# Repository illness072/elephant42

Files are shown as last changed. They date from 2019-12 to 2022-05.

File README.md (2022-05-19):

# elephant42 (🐘42)

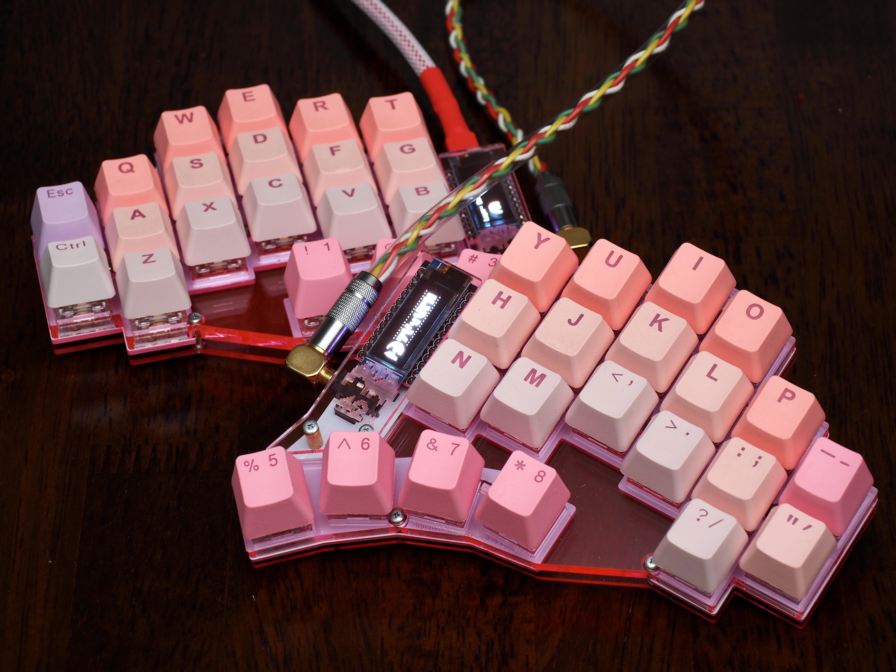
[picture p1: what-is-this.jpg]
what-is-this


## plates

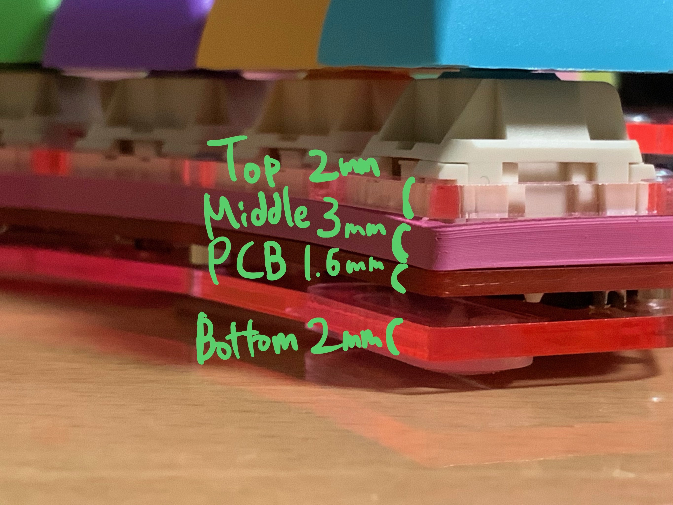
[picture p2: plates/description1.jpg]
plate1
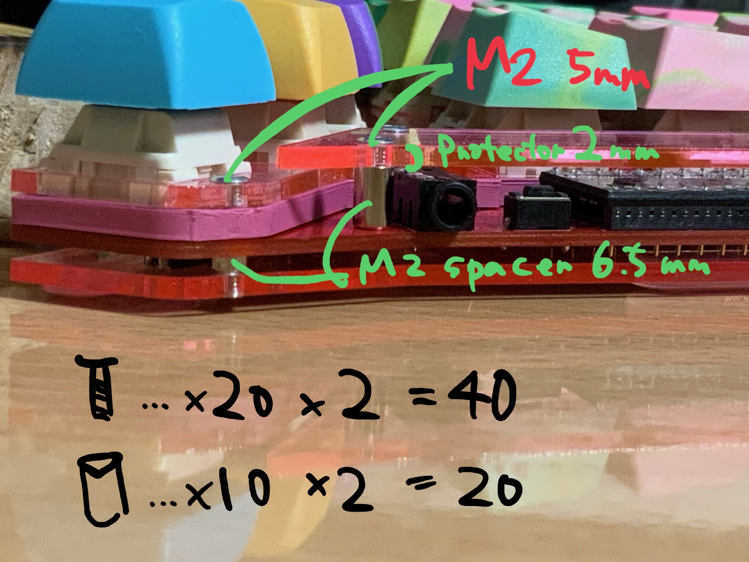
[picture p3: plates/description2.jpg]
plate2
|||
|--|--|
|dxf data in plates/|sandwitch mount with 6.5mm spacer|

## pcb

dependency on

  - https://github.com/foostan/kbd/tree/master/kicad-footprints/kbd.pretty

## cases

currently, not compatible with some switches.

## assembly

- [Build Guide (Japanese)](docs/build-guide.md)
- [Build Guide (English)](docs/build-guide-english.md)

## license?

Beerware!!

Come drink beer in Tokyo with me!! 🍺🍺🍺

## poor english?

Sorry, it's Google Translate.

# A small favor.

Could you generate a Gerber file from the origin/footprint branch and actually manufacture the PCB? 
We have implemented a fix for the footprint library link error and KiCAD6 support, but we have not yet been able to manufacture a PCB and test that it really works.
I would be most grateful if you could actually manufacture the PCB based on the footprint branch, check that it works, and report the results to me via Issue in this repository, my twitter, etc.
Thanks in advance.

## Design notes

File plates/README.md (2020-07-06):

# elephant42 アクリルプレートデータ

## トッププレートおよびボトムプレート、Pro Micro 保護プレート

acril-cut-2mm-A4.dxf

- トッププレートおよびボトムプレート、Pro Micro 保護プレートのカットデータです。
- 外枠が A4 サイズ、カット線を赤で作成しています
- 彫刻はありません。お好みに応じて追加してください
- プレート厚は 2mm を指定してください。

## ミドルプレート

acril-cut-3mm-A5.dxf

- ミドルプレートと、おまけで Pro Micro 保護プレートの厚め版をカットできるデータです
- 外枠が A5 サイズ、カット線を赤で作成しています
- 彫刻はありません。お好みに応じて追加してください
- プレート厚は 3mm を指定してください。

middle-plate-3Dprint.stl

- ミドルプレートの 3D プリントデータです。
  - 不透明素材にも対応するため、アクリルカット版のミドルプレートとは形状が異なります

## (発注用データ)

yusha/

- 実際に遊舎工房に発注するのに使用しているデータです。
  - 管理が面倒なので一緒に置いてますが、使うことはないと思います。

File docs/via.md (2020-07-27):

# VIA 対応ファームウェア

上記をどれだけ頑張っても**どーーーーーしても**環境構築がうまくいかない、コマンドラインにアレルギーがある、
GUI以外を使うわけにいかない事情がある等という方のために、VIA対応ファームウェアを用意しておきました。

[elephant42_via.hex](https://raw.githubusercontent.com/illness072/elephant42/master/via/elephant42_via.hex)

をダウンロードし、

[（初心者編）自作キーボードにファームウェアを書き込む - 自作キーボード温泉街の歩き方](https://salicylic-acid3.hatenablog.com/entry/qmk-toolbox)

を参考にファームウェアを書き込み、

[（初心者編）VIAを使ってキーマップを書き換えよう - 自作キーボード温泉街の歩き方](https://salicylic-acid3.hatenablog.com/entry/via-manual)

を参考にキーマップをいじることができます。

ただし、こちらの方法については

- QMK が提供するオフィシャルな手法ではない
- ファームウェアサイズが肥大化し、OLED ドライバサポートと共存させることができない
- ProMicro の EEPROM 書き込み回数を不用意に浪費しそうで怖い
- 何か問題が起きたときのトラブルシュートがやり辛い
- GUIであることが初心者向けであるとは限らない
- けっきょくQMKをわかってないと(特に40%以下のキーボードの設定は)厳しい
- 簡易ではあるが不完全な方法を安直に勧めるのはむしろ初心者をばかにしている

など、さまざまな問題点・懸念点があると考えており、何より elephant42 作者である私の好みではない理由により、**非推奨・サポート対象外** とさせて頂きます。

一時的な対処に使う場合や、どうしてもダメだったときの保険程度の手段と考えて、まずは QMK 本来の使用法を習熟するよう頑張ってみてください。

なお上級者の方がわかった上で運用する分には何の問題もありません。

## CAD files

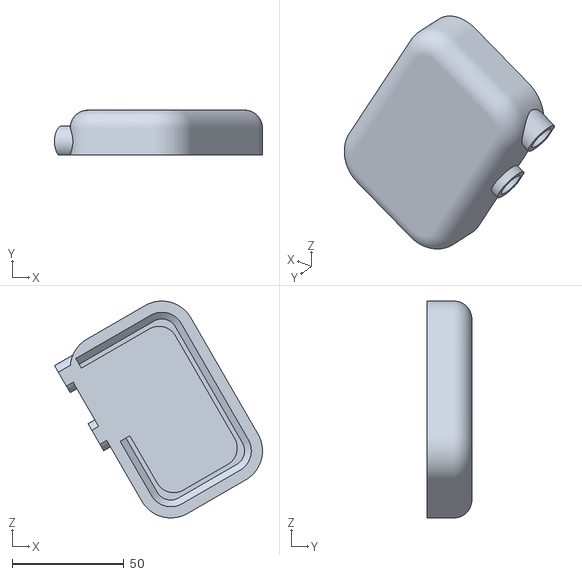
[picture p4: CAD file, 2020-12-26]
cases/v2/parmlestR.stl
93.0 x 20.0 x 97.0

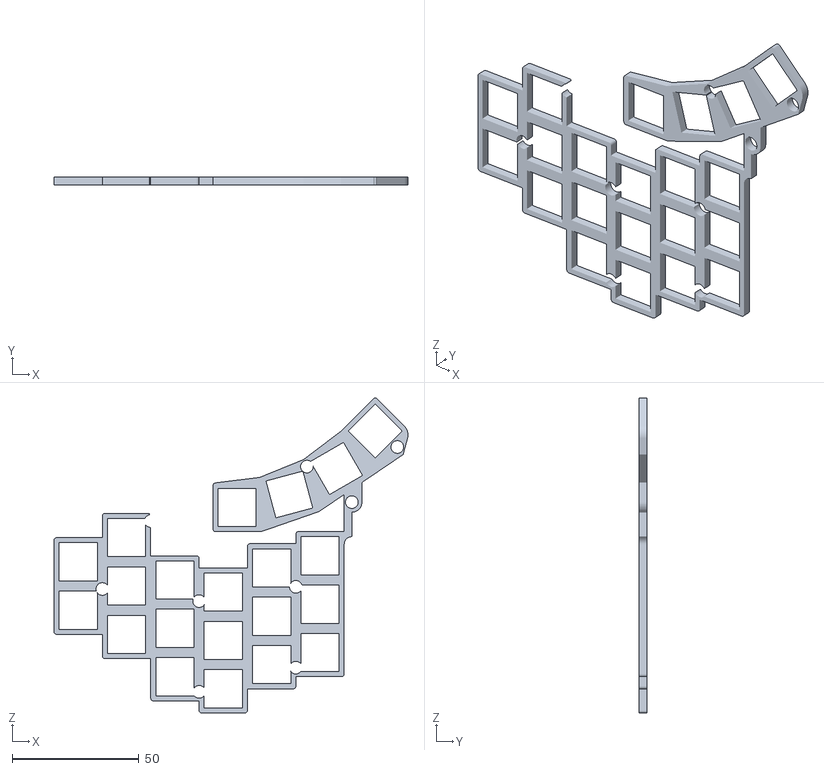
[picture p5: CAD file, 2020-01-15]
plates/middle-plate-3Dprint.stl
139.4 x 3.00 x 124.0

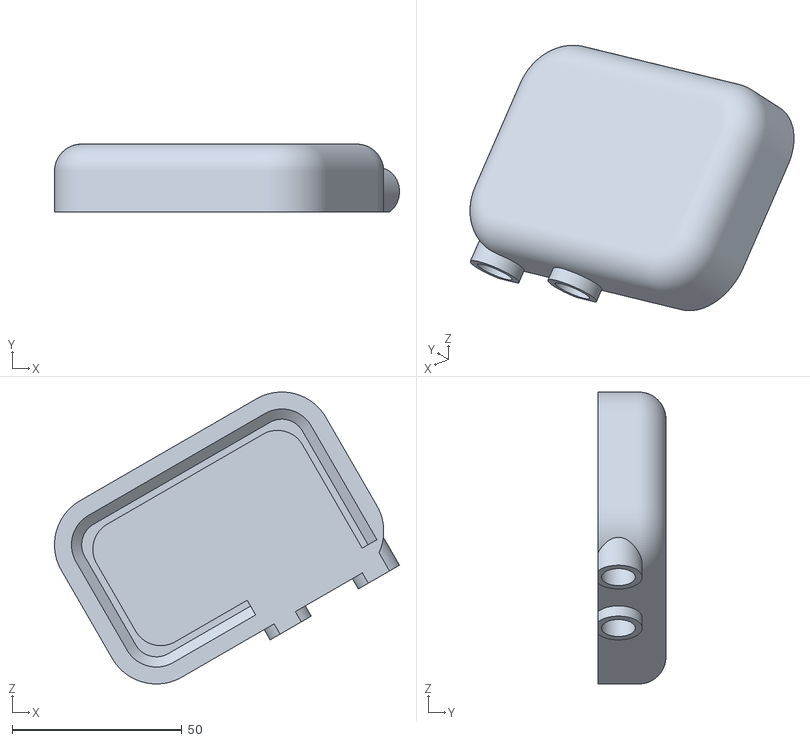
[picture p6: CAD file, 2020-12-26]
cases/v2/parmlestL.stl
101.6 x 20.0 x 86.0

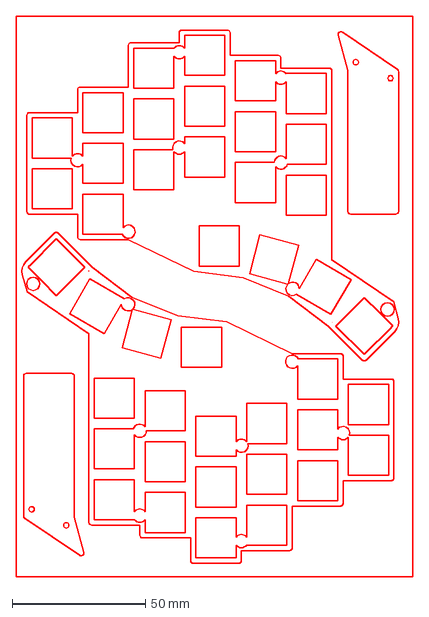
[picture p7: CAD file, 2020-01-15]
plates/acril-cut-3mm-A5.dxf
148.5 x 210.0 mm

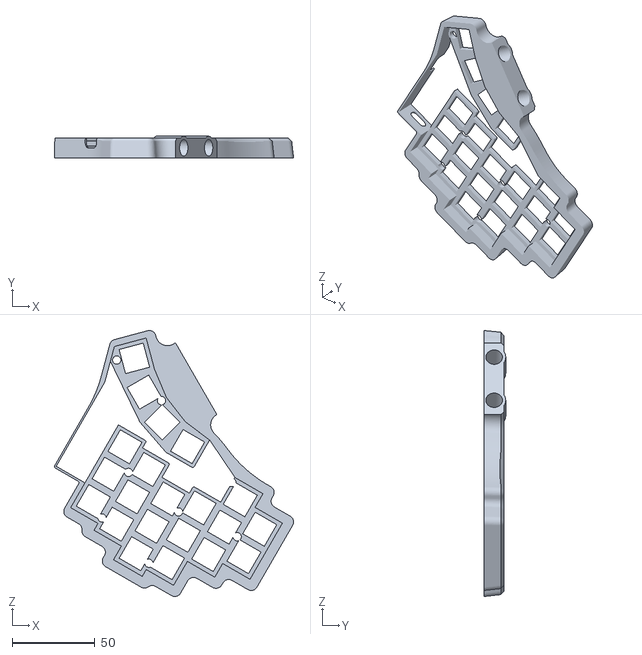
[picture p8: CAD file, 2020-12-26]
cases/v2/hangerR.stl
144.3 x 13.0 x 160.4

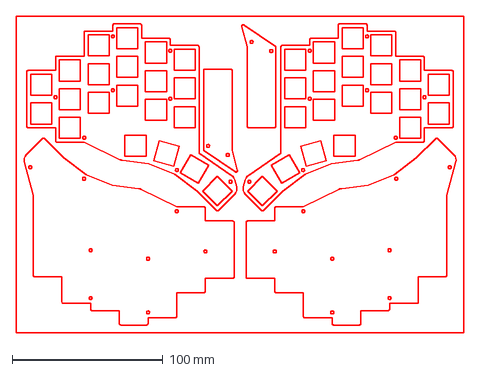
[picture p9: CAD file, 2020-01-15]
plates/acril-cut-2mm-A4.dxf
297.0 x 210.0 mm

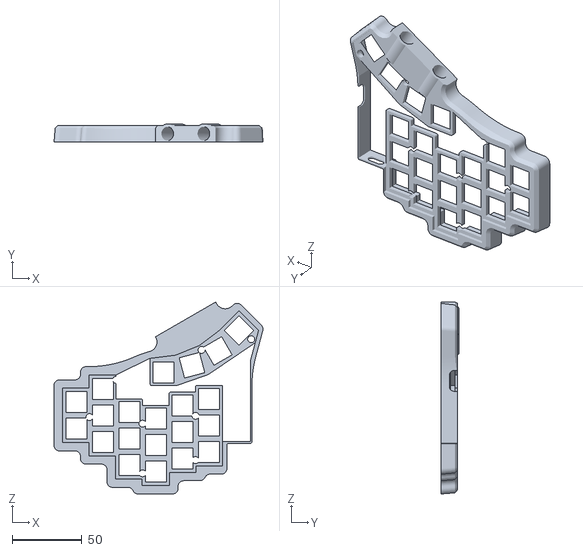
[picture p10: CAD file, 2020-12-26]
cases/v2/hangerL.stl
150.2 x 13.0 x 138.0

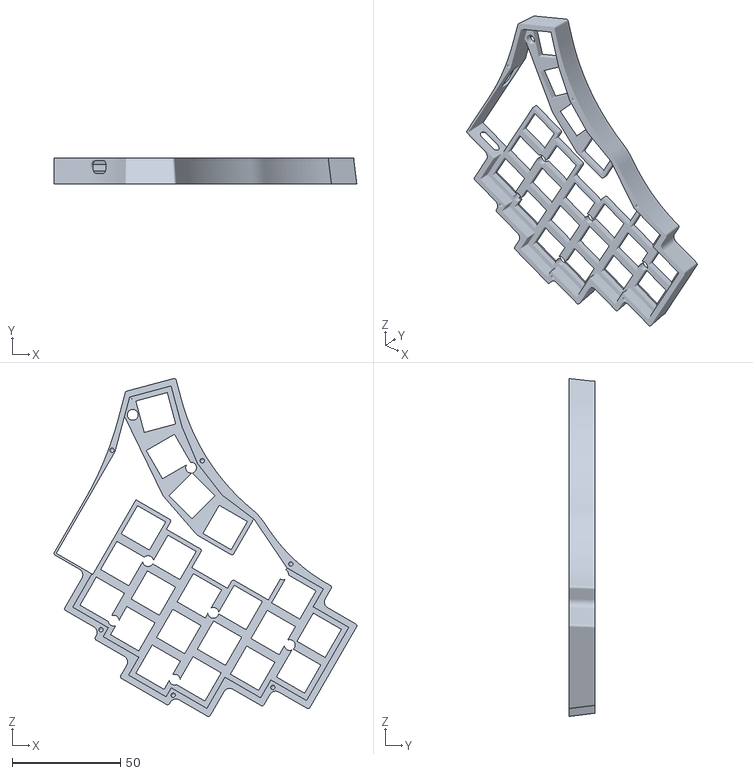
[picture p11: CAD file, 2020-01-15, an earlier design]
cases/v0/middle-hanger_R.stl
140.0 x 12.2 x 156.4

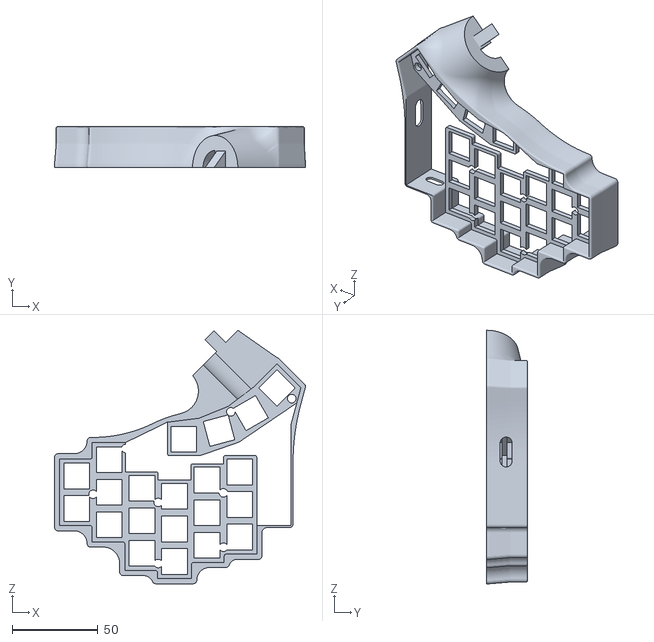
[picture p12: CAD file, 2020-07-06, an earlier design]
cases/v1/hanger-L.stl
146.8 x 24.0 x 148.3

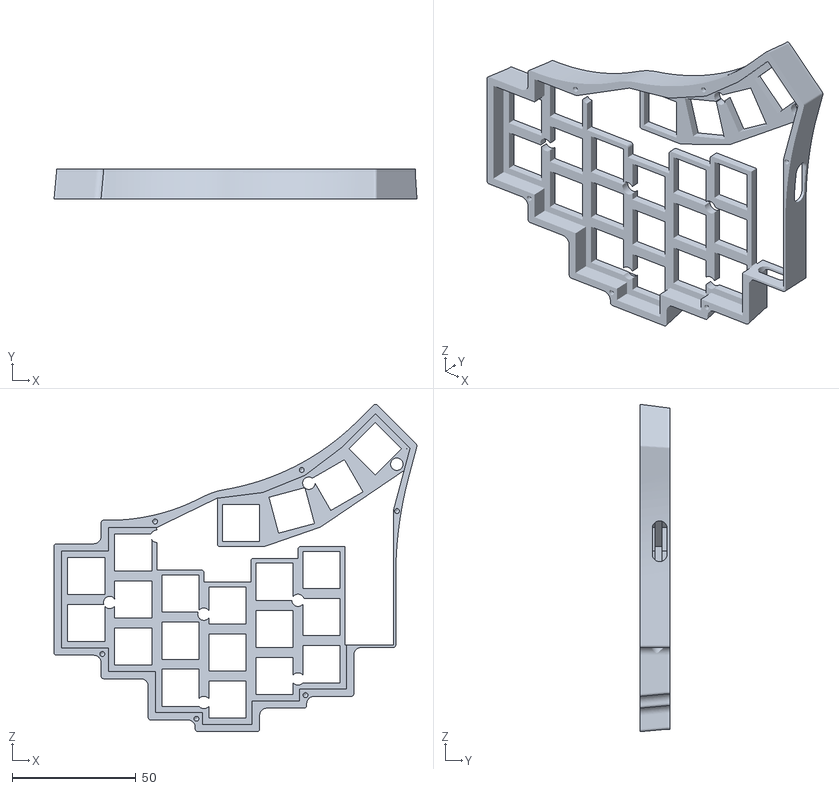
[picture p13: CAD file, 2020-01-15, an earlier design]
cases/v0/middle-hanger_L.stl
146.9 x 12.2 x 132.5

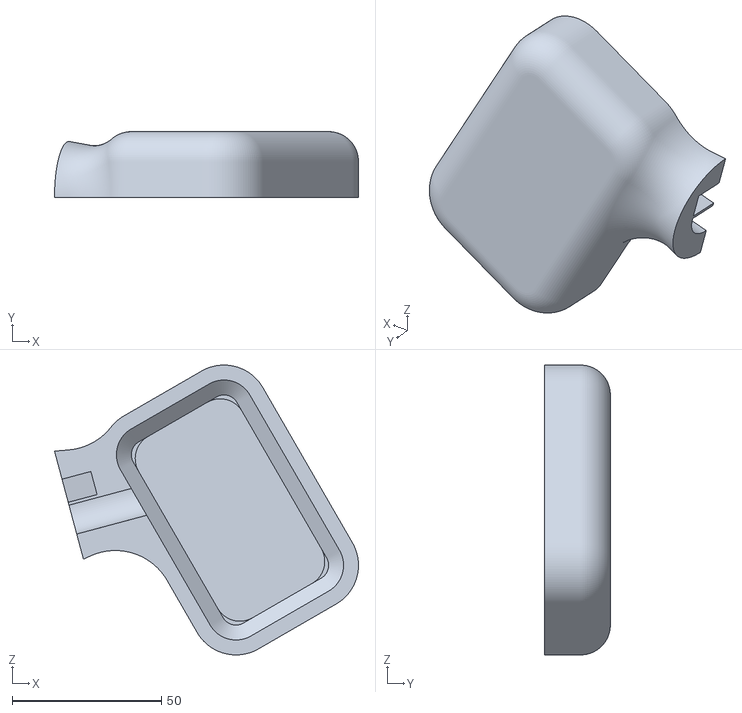
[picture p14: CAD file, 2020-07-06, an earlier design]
cases/v1/parmlest-R.stl
101.7 x 22.0 x 97.0

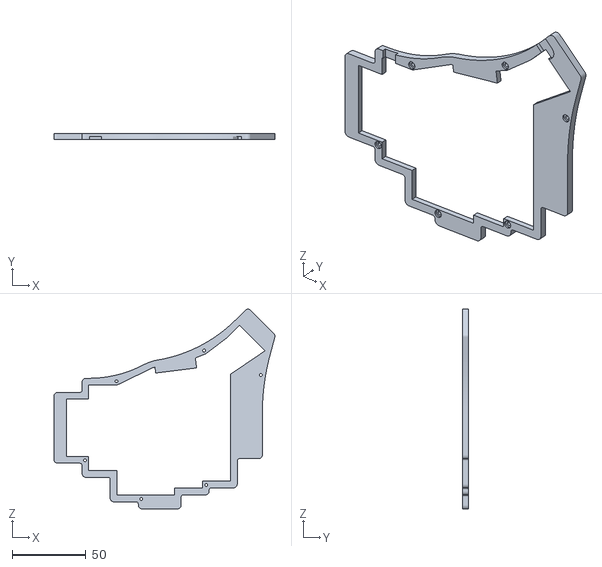
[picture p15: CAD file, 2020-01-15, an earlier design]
cases/v0/parmlest-base_L.stl
149.9 x 4.00 x 135.5

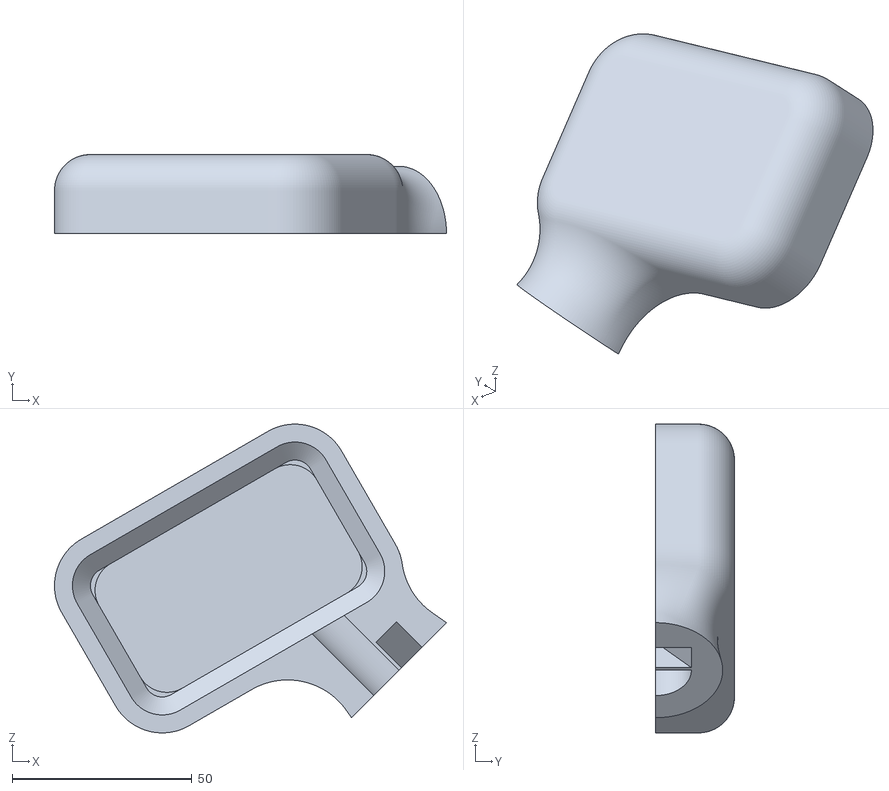
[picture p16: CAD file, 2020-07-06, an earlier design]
cases/v1/parmlest-L.stl
109.2 x 22.0 x 86.0

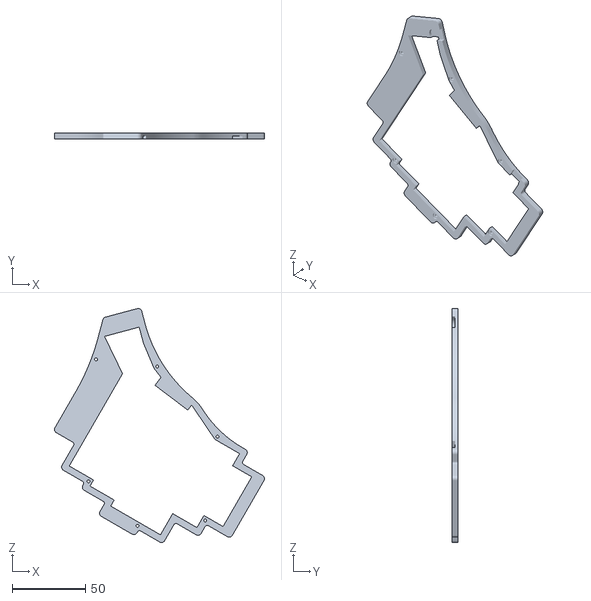
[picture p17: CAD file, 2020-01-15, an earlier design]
cases/v0/parmlest-base_R.stl
143.0 x 4.00 x 159.3

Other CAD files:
cases/v1/hanger-R.stl

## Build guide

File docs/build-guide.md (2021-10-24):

# elephant42 の組み立てかた

自作キーボードキット [elephant42](https://illness072.booth.pm/items/1775017) のビルドガイド(組立説明書)です。

**組み立ての前に、このビルドガイドを先に読んで理解して、材料・工具等を揃え、環境構築をし、最後に実際の組立作業を行ってください。**

**なにか良くわからない、うまくいかないときは、ガッカリしてそこで諦めてしまわずに[私に連絡](https://twitter.com/illness072/)してみてください。できる限り力になる努力をしたいと思います。**

「なにをしようとして」「なにをしたけど」「どうなってしまっているのか」をわかりやすいように質問して頂けるとスムーズです。

<!-- START doctoc generated TOC please keep comment here to allow auto update -->
<!-- DON'T EDIT THIS SECTION, INSTEAD RE-RUN doctoc TO UPDATE -->

- [準備](#%E6%BA%96%E5%82%99)
  - [キット内容の確認](#%E3%82%AD%E3%83%83%E3%83%88%E5%86%85%E5%AE%B9%E3%81%AE%E7%A2%BA%E8%AA%8D)
  - [必要部品の調達](#%E5%BF%85%E8%A6%81%E9%83%A8%E5%93%81%E3%81%AE%E8%AA%BF%E9%81%94)
    - [必須](#%E5%BF%85%E9%A0%88)
    - [オプション](#%E3%82%AA%E3%83%97%E3%82%B7%E3%83%A7%E3%83%B3)
  - [工具の準備](#%E5%B7%A5%E5%85%B7%E3%81%AE%E6%BA%96%E5%82%99)
    - [必要なもの](#%E5%BF%85%E8%A6%81%E3%81%AA%E3%82%82%E3%81%AE)
    - [あると良いもの](#%E3%81%82%E3%82%8B%E3%81%A8%E8%89%AF%E3%81%84%E3%82%82%E3%81%AE)
    - [買い物をする上で参考になるもの](#%E8%B2%B7%E3%81%84%E7%89%A9%E3%82%92%E3%81%99%E3%82%8B%E4%B8%8A%E3%81%A7%E5%8F%82%E8%80%83%E3%81%AB%E3%81%AA%E3%82%8B%E3%82%82%E3%81%AE)
  - [(初心者向け) はんだ付けの勉強](#%E5%88%9D%E5%BF%83%E8%80%85%E5%90%91%E3%81%91-%E3%81%AF%E3%82%93%E3%81%A0%E4%BB%98%E3%81%91%E3%81%AE%E5%8B%89%E5%BC%B7)
  - [組み立て工程全体の確認](#%E7%B5%84%E3%81%BF%E7%AB%8B%E3%81%A6%E5%B7%A5%E7%A8%8B%E5%85%A8%E4%BD%93%E3%81%AE%E7%A2%BA%E8%AA%8D)
  - [Pro Micro のもげ対策](#pro-micro-%E3%81%AE%E3%82%82%E3%81%92%E5%AF%BE%E7%AD%96)
- [ファームウェアを書き込む](#%E3%83%95%E3%82%A1%E3%83%BC%E3%83%A0%E3%82%A6%E3%82%A7%E3%82%A2%E3%82%92%E6%9B%B8%E3%81%8D%E8%BE%BC%E3%82%80)
  - [Remap(VIA) 対応ファームウェアを仕様する場合](#remapvia-%E5%AF%BE%E5%BF%9C%E3%83%95%E3%82%A1%E3%83%BC%E3%83%A0%E3%82%A6%E3%82%A7%E3%82%A2%E3%82%92%E4%BB%95%E6%A7%98%E3%81%99%E3%82%8B%E5%A0%B4%E5%90%88)
  - [OLEDを使用する場合 (あるいは、こだわり派/分かってる人向け情報)](#oled%E3%82%92%E4%BD%BF%E7%94%A8%E3%81%99%E3%82%8B%E5%A0%B4%E5%90%88-%E3%81%82%E3%82%8B%E3%81%84%E3%81%AF%E3%81%93%E3%81%A0%E3%82%8F%E3%82%8A%E6%B4%BE%E5%88%86%E3%81%8B%E3%81%A3%E3%81%A6%E3%82%8B%E4%BA%BA%E5%90%91%E3%81%91%E6%83%85%E5%A0%B1)
- [ハードウェアの組み立て](#%E3%83%8F%E3%83%BC%E3%83%89%E3%82%A6%E3%82%A7%E3%82%A2%E3%81%AE%E7%B5%84%E3%81%BF%E7%AB%8B%E3%81%A6)
  - [メイン基板 (PCB) の分割](#%E3%83%A1%E3%82%A4%E3%83%B3%E5%9F%BA%E6%9D%BF-pcb-%E3%81%AE%E5%88%86%E5%89%B2)
    - [(オプション) PCB 側面の色塗り](#%E3%82%AA%E3%83%97%E3%82%B7%E3%83%A7%E3%83%B3-pcb-%E5%81%B4%E9%9D%A2%E3%81%AE%E8%89%B2%E5%A1%97%E3%82%8A)
  - [Pro Micro とコンスルーのはんだ付け](#pro-micro-%E3%81%A8%E3%82%B3%E3%83%B3%E3%82%B9%E3%83%AB%E3%83%BC%E3%81%AE%E3%81%AF%E3%82%93%E3%81%A0%E4%BB%98%E3%81%91)
  - [(オプション) バックライト/アンダーグロウ LED の取り付け](#%E3%82%AA%E3%83%97%E3%82%B7%E3%83%A7%E3%83%B3-%E3%83%90%E3%83%83%E3%82%AF%E3%83%A9%E3%82%A4%E3%83%88%E3%82%A2%E3%83%B3%E3%83%80%E3%83%BC%E3%82%B0%E3%83%AD%E3%82%A6-led-%E3%81%AE%E5%8F%96%E3%82%8A%E4%BB%98%E3%81%91)
    - [LED の動作確認方法](#led-%E3%81%AE%E5%8B%95%E4%BD%9C%E7%A2%BA%E8%AA%8D%E6%96%B9%E6%B3%95)
    - [バックライト LED の取り付け](#%E3%83%90%E3%83%83%E3%82%AF%E3%83%A9%E3%82%A4%E3%83%88-led-%E3%81%AE%E5%8F%96%E3%82%8A%E4%BB%98%E3%81%91)
    - [アンダーグロウ LED の取り付け](#%E3%82%A2%E3%83%B3%E3%83%80%E3%83%BC%E3%82%B0%E3%83%AD%E3%82%A6-led-%E3%81%AE%E5%8F%96%E3%82%8A%E4%BB%98%E3%81%91)
    - [LED 取り付け トラブルシューティング](#led-%E5%8F%96%E3%82%8A%E4%BB%98%E3%81%91-%E3%83%88%E3%83%A9%E3%83%96%E3%83%AB%E3%82%B7%E3%83%A5%E3%83%BC%E3%83%86%E3%82%A3%E3%83%B3%E3%82%B0)
  - [ダイオードの取り付け](#%E3%83%80%E3%82%A4%E3%82%AA%E3%83%BC%E3%83%89%E3%81%AE%E5%8F%96%E3%82%8A%E4%BB%98%E3%81%91)
  - [スイッチソケットの取り付け](#%E3%82%B9%E3%82%A4%E3%83%83%E3%83%81%E3%82%BD%E3%82%B1%E3%83%83%E3%83%88%E3%81%AE%E5%8F%96%E3%82%8A%E4%BB%98%E3%81%91)
  - [TRRS ジャック、リセットスイッチの取り付け](#trrs-%E3%82%B8%E3%83%A3%E3%83%83%E3%82%AF%E3%83%AA%E3%82%BB%E3%83%83%E3%83%88%E3%82%B9%E3%82%A4%E3%83%83%E3%83%81%E3%81%AE%E5%8F%96%E3%82%8A%E4%BB%98%E3%81%91)
  - [(オプション) OLED の取り付け](#%E3%82%AA%E3%83%97%E3%82%B7%E3%83%A7%E3%83%B3-oled-%E3%81%AE%E5%8F%96%E3%82%8A%E4%BB%98%E3%81%91)
  - [動作確認](#%E5%8B%95%E4%BD%9C%E7%A2%BA%E8%AA%8D)
    - [動作確認 トラブルシューティング](#%E5%8B%95%E4%BD%9C%E7%A2%BA%E8%AA%8D-%E3%83%88%E3%83%A9%E3%83%96%E3%83%AB%E3%82%B7%E3%83%A5%E3%83%BC%E3%83%86%E3%82%A3%E3%83%B3%E3%82%B0)
    - [(OLEDを使用する場合) OLED の動作確認](#oled%E3%82%92%E4%BD%BF%E7%94%A8%E3%81%99%E3%82%8B%E5%A0%B4%E5%90%88-oled-%E3%81%AE%E5%8B%95%E4%BD%9C%E7%A2%BA%E8%AA%8D)
    - [フラックスの洗浄](#%E3%83%95%E3%83%A9%E3%83%83%E3%82%AF%E3%82%B9%E3%81%AE%E6%B4%97%E6%B5%84)
  - [ねじ留め](#%E3%81%AD%E3%81%98%E7%95%99%E3%82%81)
  - [(オプション) 完成を喜ぶ](#%E3%82%AA%E3%83%97%E3%82%B7%E3%83%A7%E3%83%B3-%E5%AE%8C%E6%88%90%E3%82%92%E5%96%9C%E3%81%B6)
- [カスタマイズする](#%E3%82%AB%E3%82%B9%E3%82%BF%E3%83%9E%E3%82%A4%E3%82%BA%E3%81%99%E3%82%8B)
  - [キーマップのカスタマイズ](#%E3%82%AD%E3%83%BC%E3%83%9E%E3%83%83%E3%83%97%E3%81%AE%E3%82%AB%E3%82%B9%E3%82%BF%E3%83%9E%E3%82%A4%E3%82%BA)
    - [Remap を使用しない場合](#remap-%E3%82%92%E4%BD%BF%E7%94%A8%E3%81%97%E3%81%AA%E3%81%84%E5%A0%B4%E5%90%88)
  - [OLED のカスタマイズ](#oled-%E3%81%AE%E3%82%AB%E3%82%B9%E3%82%BF%E3%83%9E%E3%82%A4%E3%82%BA)
  - [アクリルプレートのカスタマイズ](#%E3%82%A2%E3%82%AF%E3%83%AA%E3%83%AB%E3%83%97%E3%83%AC%E3%83%BC%E3%83%88%E3%81%AE%E3%82%AB%E3%82%B9%E3%82%BF%E3%83%9E%E3%82%A4%E3%82%BA)
  - [専用ケースの 3D プリント](#%E5%B0%82%E7%94%A8%E3%82%B1%E3%83%BC%E3%82%B9%E3%81%AE-3d-%E3%83%97%E3%83%AA%E3%83%B3%E3%83%88)
- [日々のお手入れ](#%E6%97%A5%E3%80%85%E3%81%AE%E3%81%8A%E6%89%8B%E5%85%A5%E3%82%8C)
  - [掃除](#%E6%8E%83%E9%99%A4)
  - [ファームウェアアップデート](#%E3%83%95%E3%82%A1%E3%83%BC%E3%83%A0%E3%82%A6%E3%82%A7%E3%82%A2%E3%82%A2%E3%83%83%E3%83%97%E3%83%87%E3%83%BC%E3%83%88)
- [さいごに](#%E3%81%95%E3%81%84%E3%81%94%E3%81%AB)

<!-- END doctoc generated TOC please keep comment here to allow auto update -->

# 準備

## キット内容の確認

内容物に不足や破損などがないか確認してください。

各アクリルプレートは表裏面に保護紙が貼られています。すぐ剥がしても良いですが、指紋やホコリや汚れがつかないよう組付け直前まで剥さないでおいたほうがいいです。

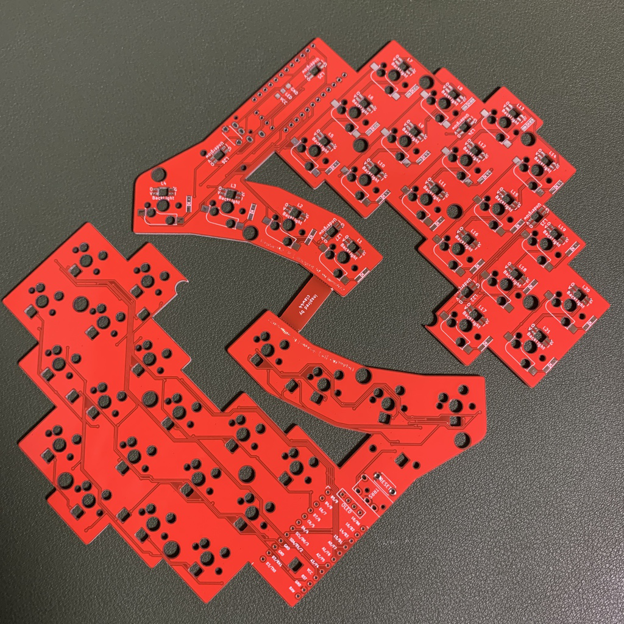
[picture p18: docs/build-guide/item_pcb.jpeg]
基板(PCB)
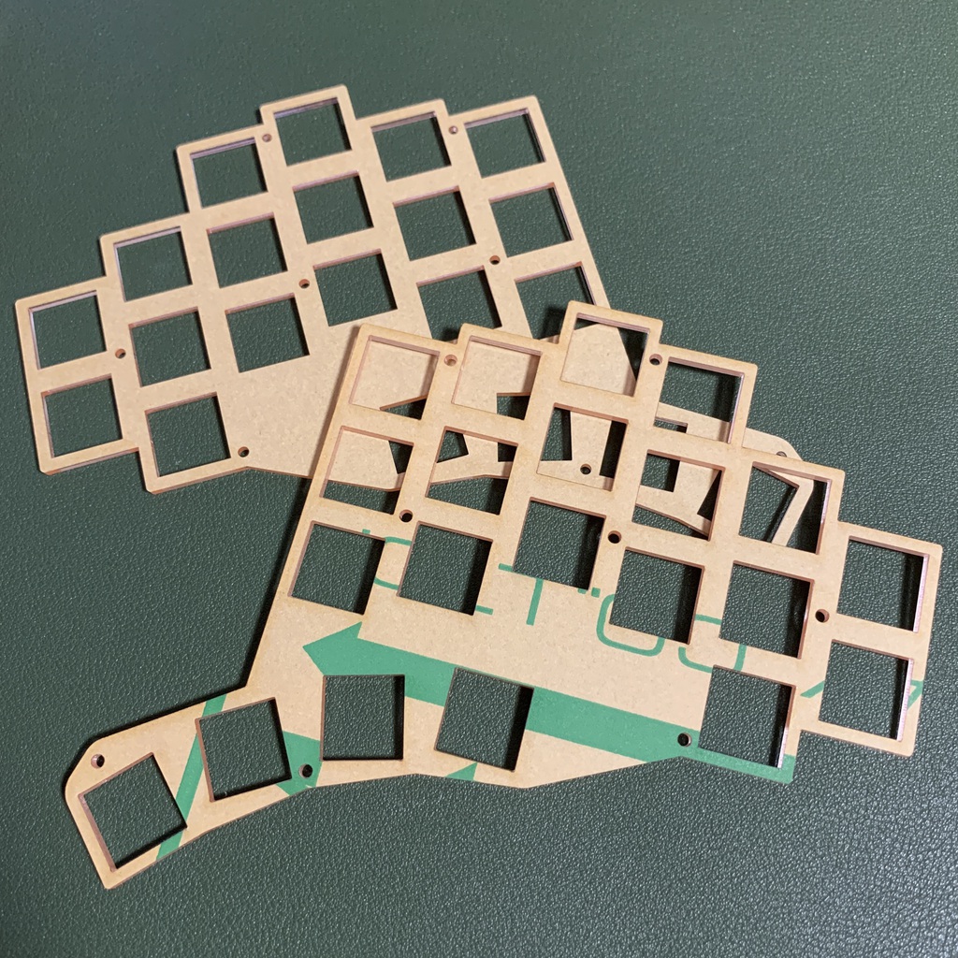
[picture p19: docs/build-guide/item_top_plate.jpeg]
トッププレート
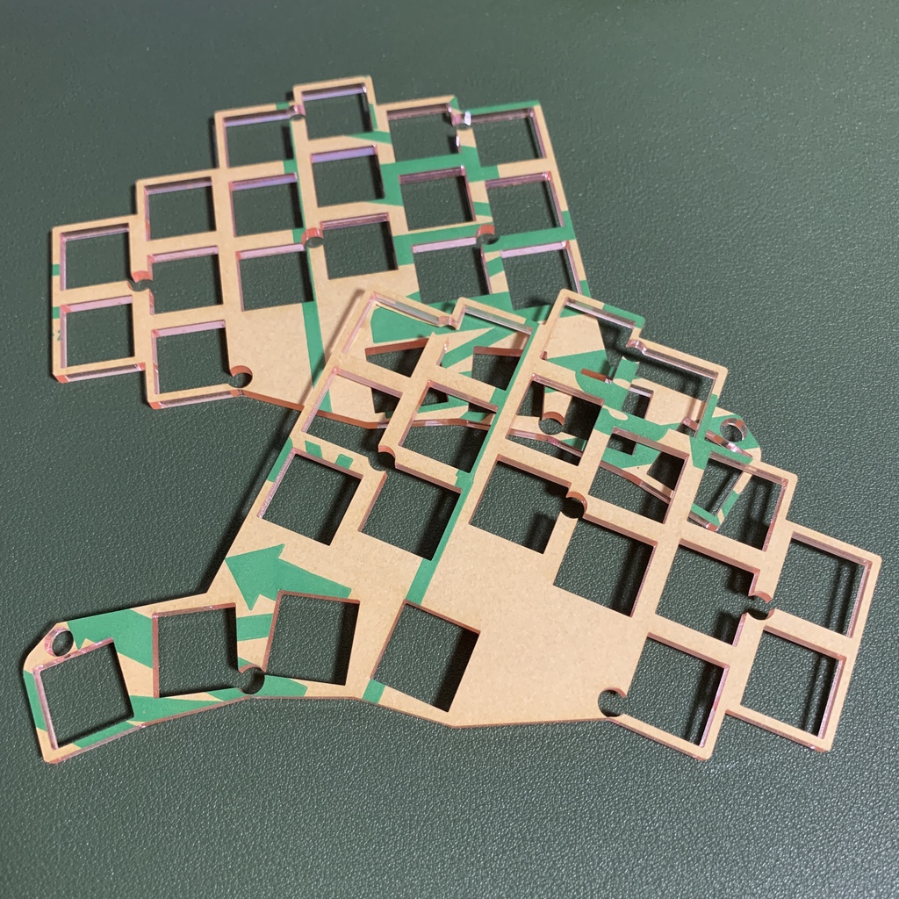
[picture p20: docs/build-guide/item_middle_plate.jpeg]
ミドルプレート
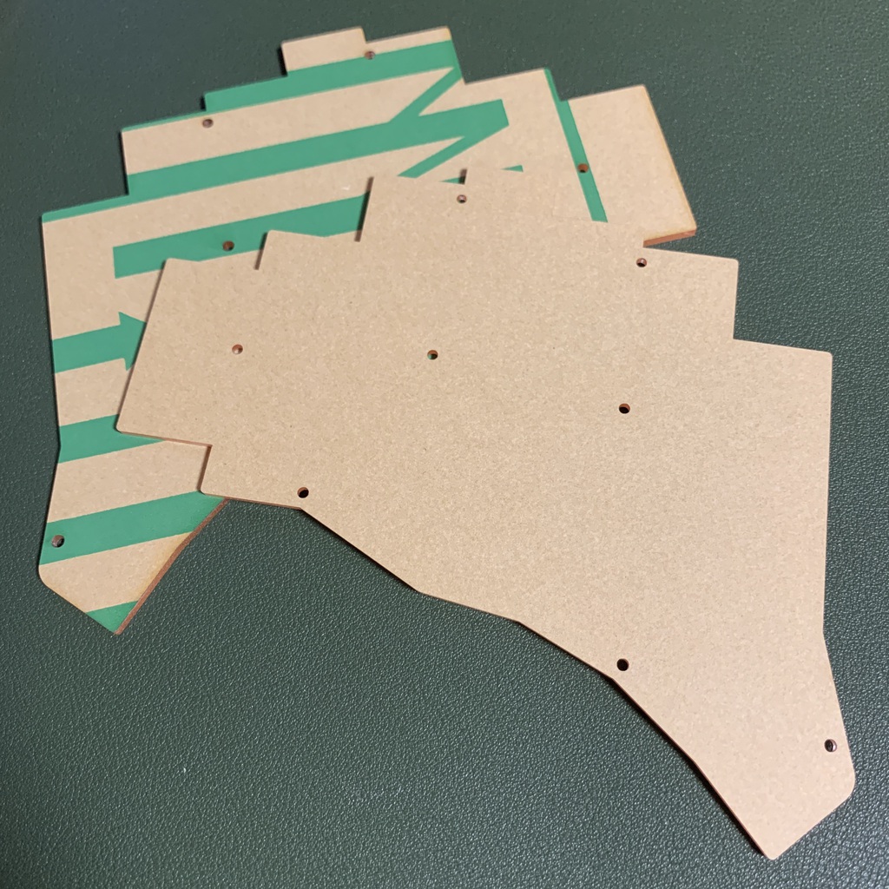
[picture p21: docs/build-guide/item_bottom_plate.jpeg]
ボトムプレート
|  |  |  |  |
|:--:|:--:|:--:|:--:|
|メイン基板(PCB) ... 1枚<br/>**※1**|トッププレート ... 2枚<br/>(薄くて穴が小さい方)|ミドルプレート ... 2枚<br/>(厚くて穴が大きい方)|ボトムプレート ... 2枚|
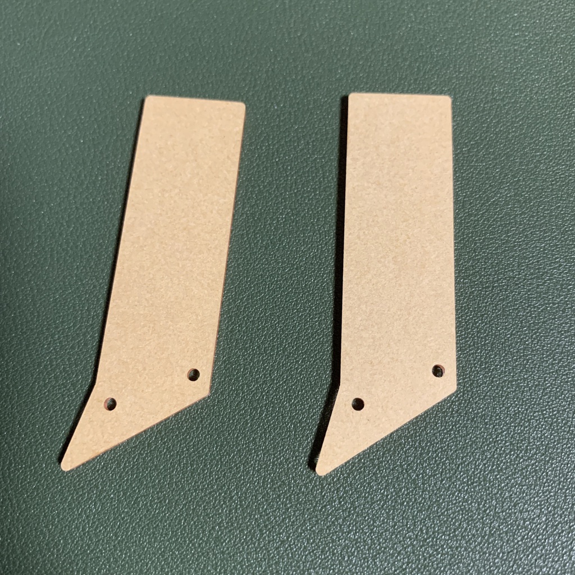
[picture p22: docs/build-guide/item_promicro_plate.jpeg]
ProMicro 保護プレート
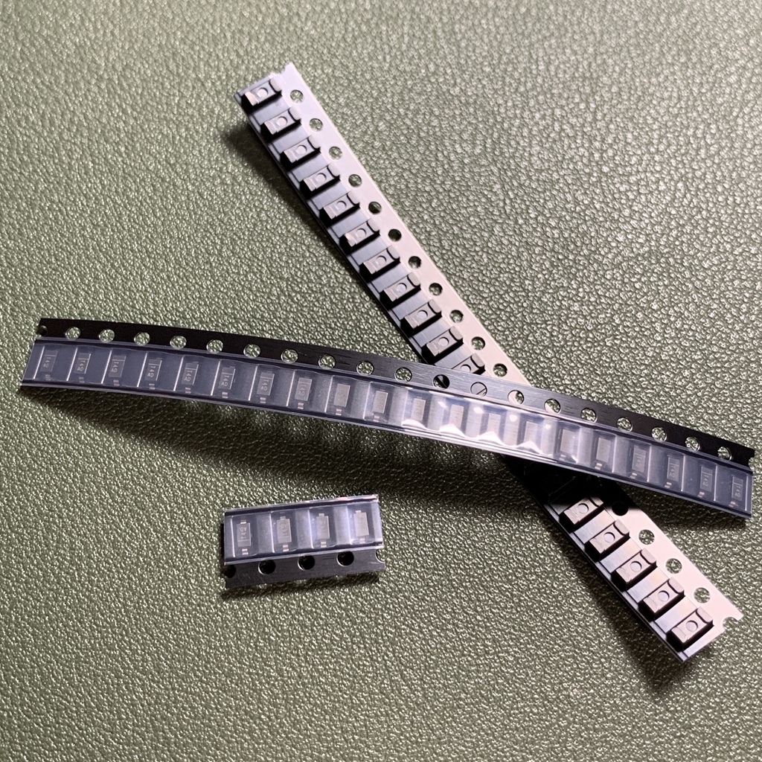
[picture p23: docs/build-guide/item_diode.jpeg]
ダイオード
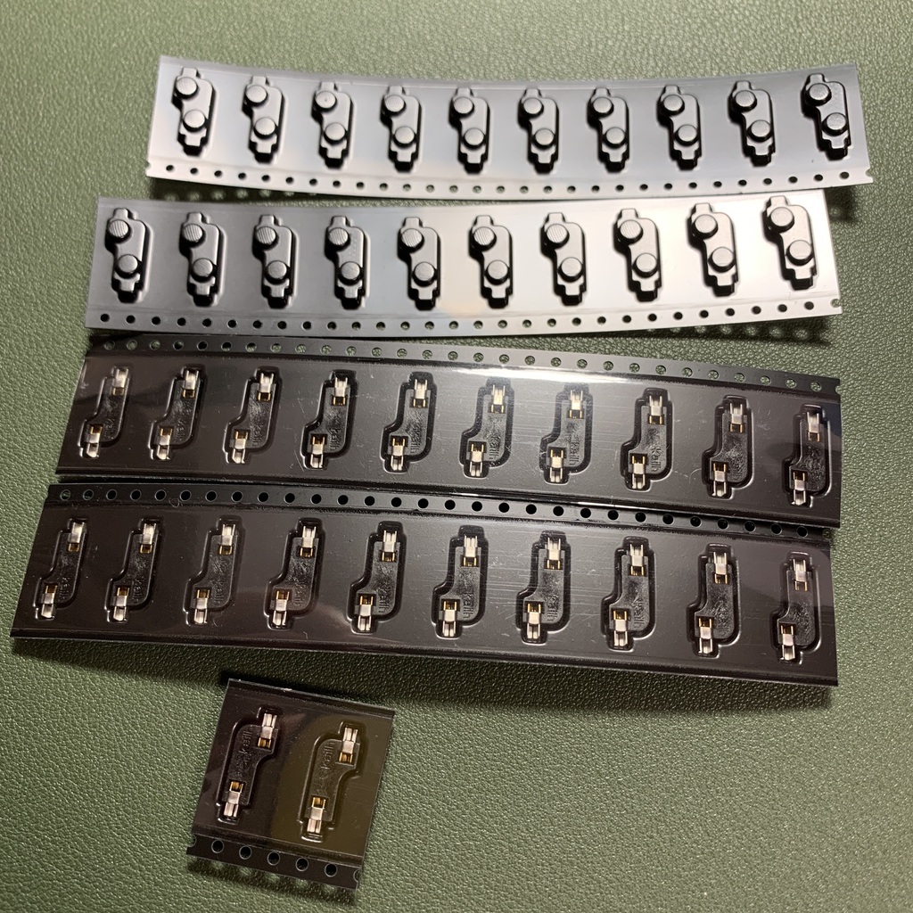
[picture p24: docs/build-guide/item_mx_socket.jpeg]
MX 互換スイッチ用 PCB ソケット
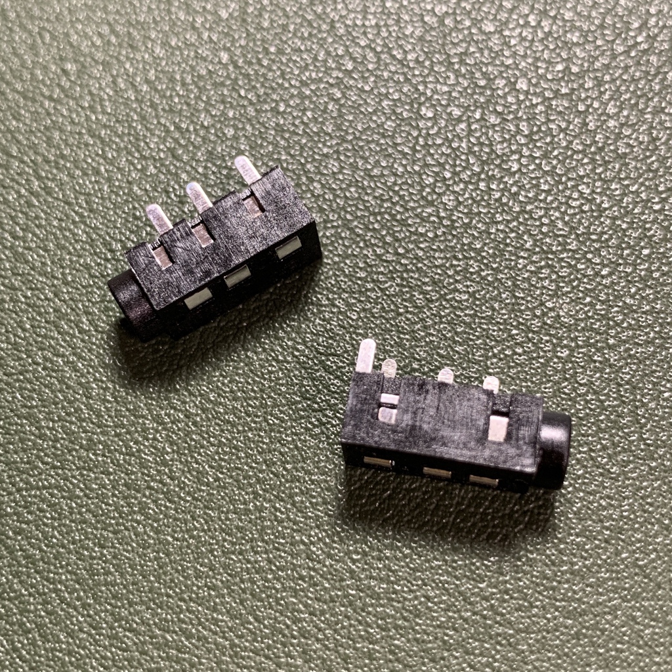
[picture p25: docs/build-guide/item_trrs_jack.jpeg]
TRRS ジャック
|  |  |  |  |
| ProMicro 保護プレート ... 2枚<br/>**※2** | ダイオード ... 44個<br/>(予備2個) | MX 互換スイッチ用<br/>PCB ソケット ... 42個 | TRRS ジャック ... 2個 |
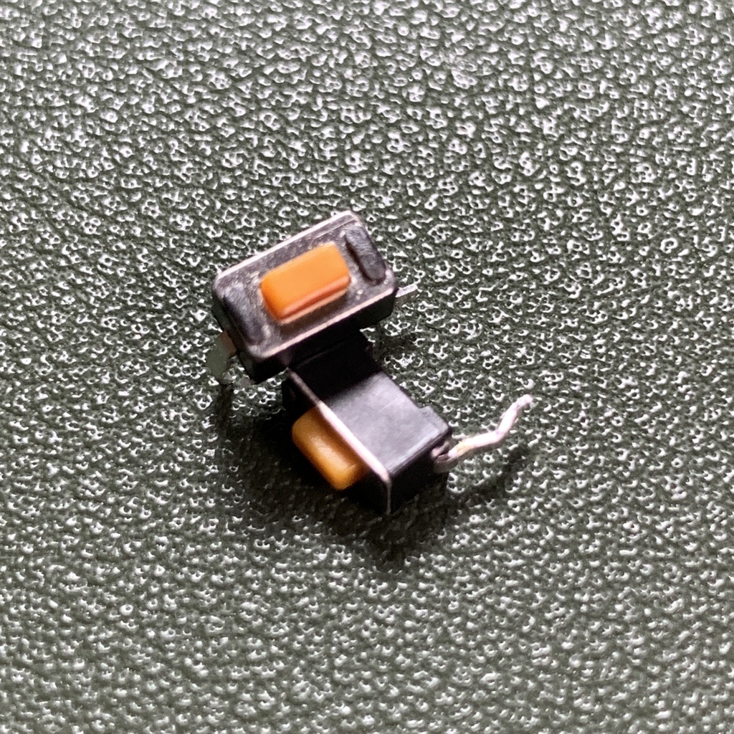
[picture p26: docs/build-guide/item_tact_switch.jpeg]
タクトスイッチ
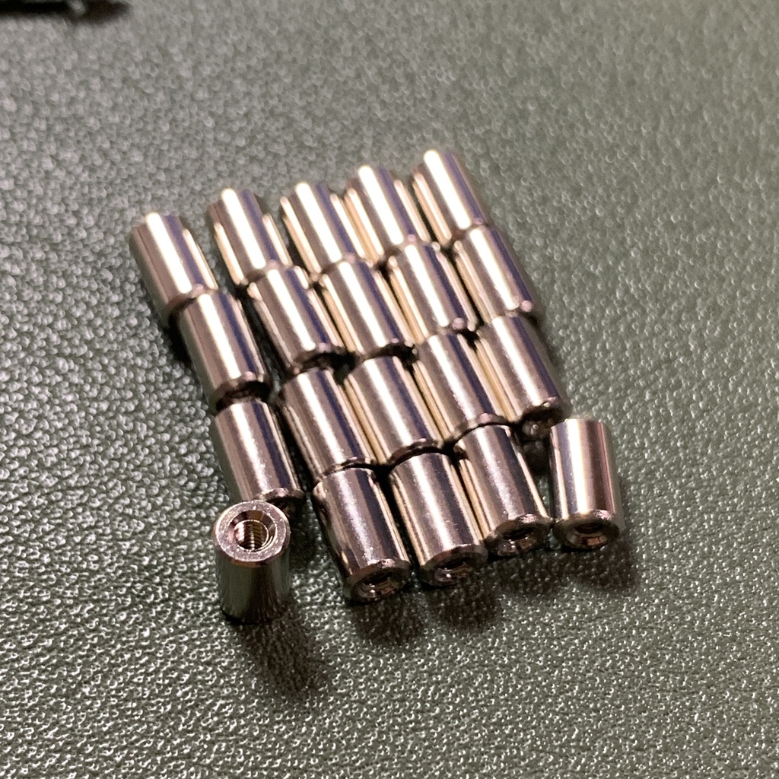
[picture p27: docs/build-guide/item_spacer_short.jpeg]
スペーサー(短)
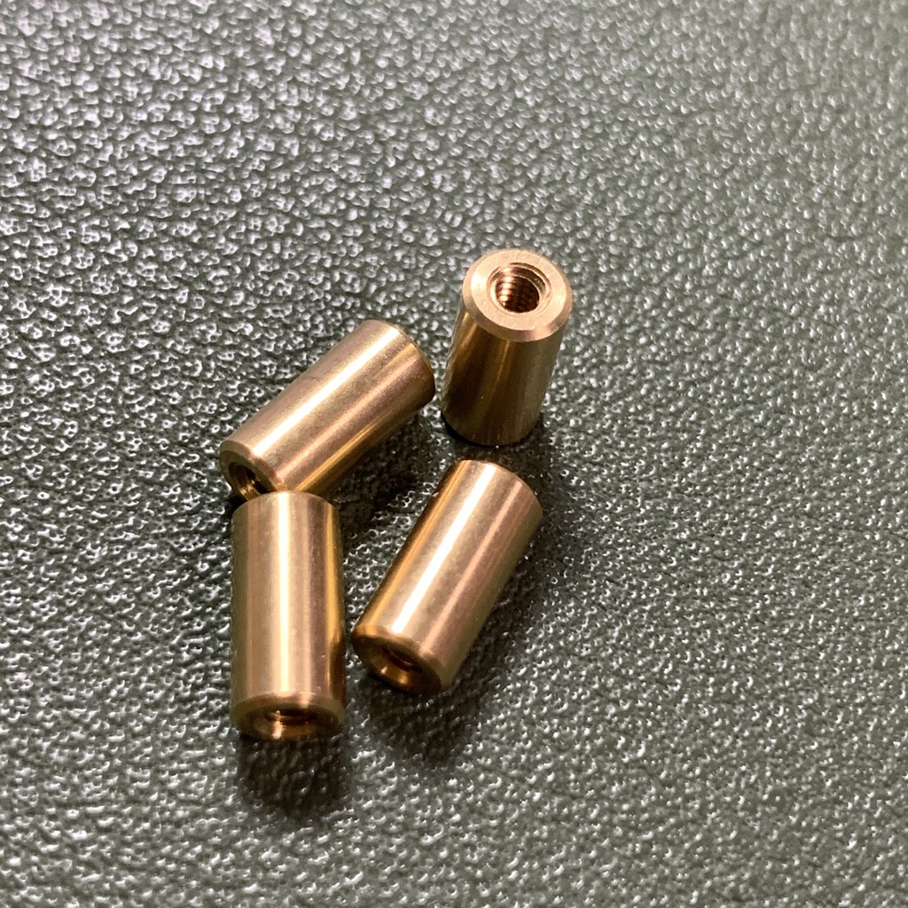
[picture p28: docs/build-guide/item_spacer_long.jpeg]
スペーサー(長)
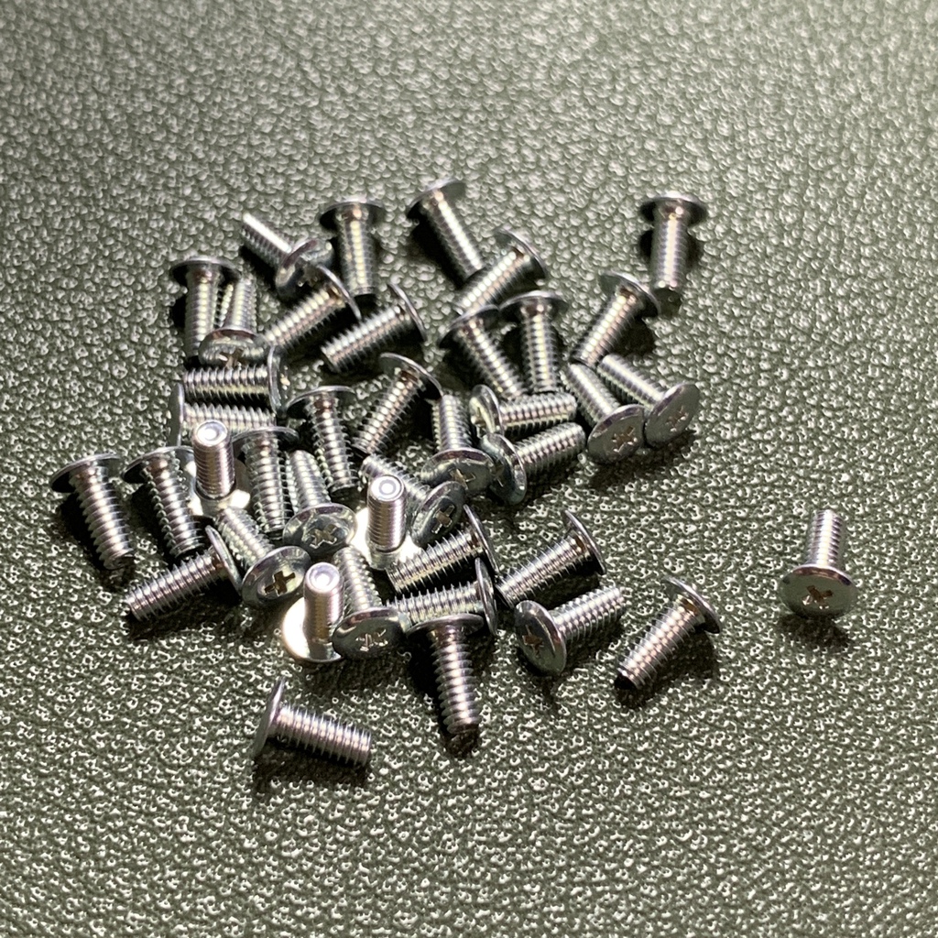
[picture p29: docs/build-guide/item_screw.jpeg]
ネジ
|  |  |  |  |
| タクトスイッチ ... 2個<br/>※色は異なる場合があります | スペーサー(短) ... 20本 | スペーサー(長) ... 4本 | ネジ ... 40本 |
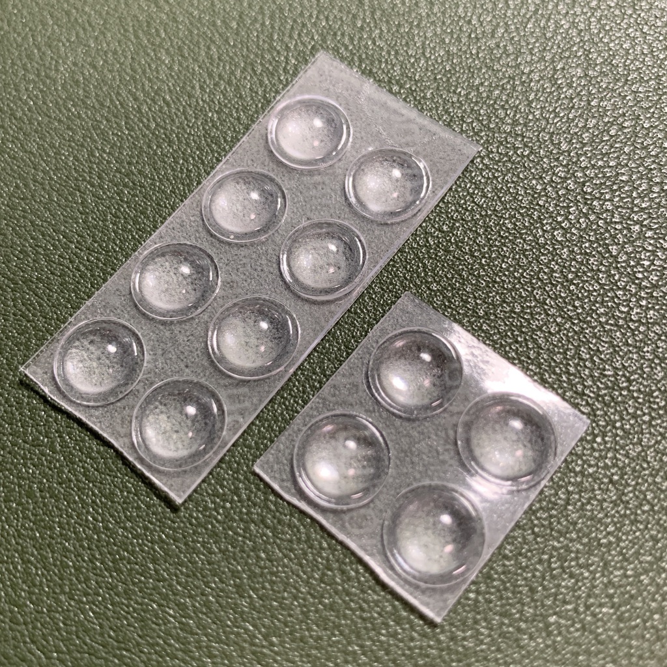
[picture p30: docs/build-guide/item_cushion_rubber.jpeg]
クッションゴム
|  ||||
| クッションゴム ... 10個 ||||

※1... v1から基板の色は白となりました。組み立て方に違いはありません。

※2... ProMicro 保護プレートは elephant42 ロゴ刻印入りの 2mm 厚のものが 2 枚、3mm 厚のものが 2 枚、計 4 枚含まれています。好みで選択してください。

## 必要部品の調達

キットに含まれていないが必要なものを購入します。

初心者向けのおすすめ購入先 (国内通販) のリンクも併せて載せておきますので参考にしてください。

### 必須

- **Pro Micro(コンスルー付き) ... 2組**
   - おすすめ購入先
     - [Pro Micro （コンスルー付き）| 遊舎工房](https://yushakobo.jp/shop/promicro-spring-pinheader/) ※2つ購入してください
     - TALP KEYBOARD
       - [Pro Micro ATmega32U4 5V/16MHz/MicroUSB2(互換品)](https://talpkeyboard.stores.jp/items/5b24504ba6e6ee7ec60063e3) ※2つ購入してください
       - [MAC8 コンスルー XB-3-2.5-12P (高さ2.5mm/12ピン/1個)](https://talpkeyboard.stores.jp/items/5e056626d790db16e2889233) ※4つ購入してください
     - Amazon などで非常に安価な Pro Micro が複数個セットで販売されていますが、結構な確率で粗悪品を掴むのでちゃんとした店で購入した方が無難です。
   - 国内キットでは同梱しているキットが多いですが、本キットは同梱していません。
   - Type-C 版や BLE 対応版などのバリエーションもあります。私は試したことないですが、多分動くと思います。
- MX 互換スイッチ ... 42個
   - おすすめ購入先
     - [Switches | 遊舎工房](https://yushakobo.jp/product-category/switches/)
     - [TALP KEYBOARD](https://talpkeyboard.stores.jp/?category_id=59cf8860ed05e668db003f5d)
   - 「Kailh ロープロファイル (Choc) スイッチ」および「Kailh Mid-Heightスイッチ」は非対応ですのでご注意ください。
- 1Uキーキャップ ... 42個
   - おすすめ購入先
     - [Keycaps | 遊舎工房](https://yushakobo.jp/product-category/keycaps/)
     - [TALP KEYBOARD](https://talpkeyboard.stores.jp/?category_id=59be183f428f2d49120007b1)
     - [Tai-Hao shop](https://shop.tai-hao.com/) ※海外
     - [ごはんキーキャップ 自作キーキャップキット - うさぎごや - BOOTH](https://booth.pm/ja/items/1783747)
   - キースイッチと同じく「Kailh ロープロファイル (Choc) スイッチ」用のキーキャップは非対応ですのでご注意ください。
- TRSケーブル ... 1本
    - AUX ケーブル、ステレオミニプラグケーブルなどとも呼ばれています。所謂イヤホンのプラグが両方についてるケーブルです。
      - Amazon などで見た目が良くて安ものが売られています
    - elephant42 が必要とするのは 3 極(黒線が2本入るタイプ)の TRS ケーブルですが、自作キーボードショップなどでよく売られている 4 極(黒線が3本入るタイプ) の TRRS ケーブルでも代用可能です。
      - [TRRSケーブル | Daily Craft Keyboard](https://shop.dailycraft.jp/products/trrs_cable_50)
      - [自作ケーブルキット | 遊舎工房](https://yushakobo.jp/shop/self-made-cable/)
      - [透ケーブル - うさぎごや - BOOTH](https://illness072.booth.pm/items/2227567)
- USB ケーブル (Type-A to Micro-B) ... 1本
    - 所謂 Micro USB ケーブルです。
      - Amazon などで見た目が良いものが売られています
      - [USBケーブル Micro B 1m | 遊舎工房](https://yushakobo.jp/shop/usb_cable_micro_b/)
      - [自作ケーブルキット | 遊舎工房](https://yushakobo.jp/shop/self-made-cable/)
      - [USB2.0ケーブル（0.6m/USB(A)オス - USB(Micro-B)オス) | TALP KEYBOARD](https://talpkeyboard.stores.jp/items/5df82904a551d528d7360c34)
    - Type-C 版 ProMicro など、Micro-Bを使用しない Pro Micro を使う場合は適切なケーブルを調達してください。

### オプション

1. OLEDモジュール（ピンソケット付き） ... 2個
    - [OLEDモジュール | 遊舎工房](https://yushakobo.jp/shop/oled/) ※ピンソケット付きを選択してください
1. SK6812MINI-E ... 54個
    - [SK6812MINI-E（10個入り） | 遊舎工房](https://shop.yushakobo.jp/collections/all-products/products/sk6812mini-e-10) ※6パック購入してください(6個余ります)
      - **従来品の「[SK6812MINI](https://yushakobo.jp/shop/sk6812mini-35/)」は互換性がないため使用できません。**
      - **※遊舎工房実店舗で購入する場合、見た目が非常に似通っている「[リバースマウント RGB LED](https://yushakobo.jp/shop/a0800rl-10/)」を誤って購入しないよう注意してください。互換性がないため使用できません。**
    - [マイコン内蔵RGBLED SK6812MINI-E(5個入): LED(発光ダイオード) 秋月電子通商-電子部品・ネット通販](https://akizukidenshi.com/catalog/g/gI-15478/) ※11パック購入してください(1個余ります  )

## 工具の準備

組み立てだけでなく、修理などでも工具は必要になります。また特に電子工作は、良い工具を使うと作業がぐっと簡単になります。
お財布と相談しつつ、なるべく良い工具を揃えると良いでしょう。

また、自宅から通いやすい場所に工作スペースがある場合は、そちらの利用も考慮すると良いかもしれません。

### 必要なもの

- はんだ
  - [goot 高密度集積基板用はんだ SD-60](https://www.amazon.co.jp//dp/B0029LGAJI/)
    - ほとんどの部品はこちらで取り付けています。正直なんでも良いです。
  - [久富電機産業 SH-43 低温はんだ](https://www.sengoku.co.jp/mod/sgk_cart/detail.php?code=6A2W-CFJP)
    - LED(SK6812mini-E) だけは高温で壊れる危険性があるため、念のためこちらを使っています
- はんだ吸い取り線
  - [goot はんだ吸取り線 CP-3015](https://www.amazon.co.jp/dp/B001PR1KPQ)
  - [はんだシュッ太郎](https://www.sunhayato.co.jp/material2/jtp03/item_1054)などがあればそれに越したことはないんでしょうけど試せたことがないです。
- はんだこて
  - [白光 ダイヤル式温度制御はんだこて FX600](https://www.amazon.co.jp/dp/B006MQD7M4)
  - **温度調整機能つきを強くおすすめします。** 私は温度調節機能なしのこてで成功できた試しがありません。
- こて台
  - [白光(HAKKO) こて台 633-01](https://www.amazon.co.jp/dp/B000TGNWCS)
- フラックス
  - [goot プリント基板フラックス BS-75B ](https://www.amazon.co.jp/dp/B004ANR7KY/)
  - なくてもできる! という人をたまに見かけますが、ほぼ間違いなく腕を自慢したい上級者です。特に LED をつける場合はほぼ必須と思ってください。
- フラックスクリーナー
  - [太洋電機産業(goot) フラックスリムーバー BS-T20B](https://www.amazon.co.jp/dp/B07JHJHTYG/)
  - 無洗浄タイプのフラックスなら不要というわけではありません。茶色くベタベタして汚らしく、また経年劣化で基板にダメージを与えるらしいので、なるべく使用するようにしてください。
- キムワイプ
  - [日本製紙クレシア キムワイプ S-200 mini 62015 1個入](https://www.amazon.co.jp/dp/B00CWA23P6)
  - ティッシュでも代用可能ですが、あまりおすすめはしません。
- ふつうのピンセット
  - ダイソーで購入したものを使用。プラモデルと共用。
- ふつうのマスキングテープ
  - ダイソーで購入したものを使用。プラモデルと共用。
- 棒ヤスリ
  - ダイソーで購入したものを使用。プラモデルと共用。
- ふつうのカッターナイフ
  - 切れればなんでも良い。今回はプラモデルで使用するデザインナイフで代用。

### あると良いもの

- 油性ペン
  - 基板側面を塗るのに使います。お好みの色を用意してください。
  - ポスカが発色良くおすすめです。マッキーやプラモデルで使用するガンダムマーカーなどでも問題ありません。
- ふつうのニッパー
  - ダイソーで購入したものを使用
  - プラモデル用の良いニッパーは刃をダメにするので共用しないことをおすすめします。
- エポキシ系接着剤
  - ダイソーで購入したものを使用
- テスター
  - ほんとはあったほうが良いと思うけど、電池と電子ブザーとリード線を雑にくっつけただけの物を使用しています
- はんだ付け用作業マット
  - ほんとはあったほうが良いと思うけど、使ってません
- カッターマット
  - 机を傷つけなければ古新聞でも本キットの外箱でも何でも良い。今回はプラモデルで使用するものを使用

### 買い物をする上で参考になるもの

先人に学ぼう。

- [Helix キーボードキットの製作に必要な工具メモ | gist.github.com](https://gist.github.com/mtei/6957107a676ddfa85bde0ae41f8fa849)
- [第8回「自作キーボードのつくりかた #2」組み立てる道具とはんだ付け編 | Youtube](https://youtu.be/LOC53FeU-QM)
- [自作キーボードを作るために必要なもの | 自作キーボード温泉街の歩き方](https://salicylic-acid3.hatenablog.com/entry/2018/11/24/%E8%87%AA%E4%BD%9C%E3%82%AD%E3%83%BC%E3%83%9C%E3%83%BC%E3%83%89%E3%82%92%E4%BD%9C%E3%82%8B%E3%81%9F%E3%82%81%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)

## (初心者向け) はんだ付けの勉強

elephant42 は完成までに最低でもおよそ200箇所、最大でおよそ440箇所をはんだ付けすることになります。

人生初だったり、中学校以来久しぶりのはんだ付け、のような人はとくに、はんだ付けのやりかたを勉強しておくと良いです。

はやく完成させたい気持ちでここを飛ばしていきなり着手してしまうと、およそろくなメにあわないです。**ほんとに。**

はんだ付けの基本動作

https://youtu.be/ZA-ehWjRfYM

ProMicro、タクトスイッチ、TRRSジャックなどを実装する際にスルーホールをはんだ付けするため、こちらの動画で学習すると効率的です。

https://youtu.be/oq3Q3n57-B0

表面実装ダイオード、LEDなどをはんだ付けする方法は、こちらの動画で学習すると効率的でした。

https://youtu.be/vqKKElJ1vw0

## 組み立て工程全体の確認

Daihuku Keyboiard チャンネルさんで素晴しい動画を作っていただいたので是非視聴してビルドの確認をしてみてください!!

自作キーボード作ってみた elephant42編 | elephant42 : Custom Mechanical Keyboard Build (https://www.youtube.com/watch?v=GmBnI3VYiT4)

ついでに高評価・チャンネル登録もしておくと良いのではないでしょうか!!!!

※ 動画が作成された当時と今現在のビルドガイドで組み立て工程に若干の違い(主にファームウェアまわり。すっごく便利になりました。)があります。混乱しないように！

## Pro Micro のもげ対策

必須ではありませんが、やっておくと悲しい思いをしなくなるので良いです。

以下の記事などを参考に、エポキシ接着剤を MicroUSB ジャック周辺に盛り付けて端子を強化します。

- [ProMicroのモゲ防止ついでにQMK_Firmwareを書き込む](https://qiita.com/hdbx/items/2f3e4ddfcadda2a5578e)
- [マスキングテープを使って、安全にProMicroのモゲ対策をする](https://cnaos.hatenablog.com/entry/2019/03/16/153754)

# ファームウェアを書き込む

さっそくはんだ付けをしたい！というはやる気持ちをグッとこらえて、まずは Pro Micro にファームウェアを書き込みます。

## Remap(VIA) 対応ファームウェアを仕様する場合

ここ最近、 Remap という非常に便利でオープンなサービスが開始され、とっても便利かつ簡単に自作キーボードを設定できるようになったので**強くオススメ**しています。

Google Chrome ブラウザより、 Remap キーボードカタログの [elephant42 ファームウェア書き込みページ](https://remap-keys.app/catalog/qAHXTqZmXu6Cd6K7jqcD/firmware) にアクセスします。

***※現在、Remap は Google Chrome または Microsoft Edge 以外のブラウザではうまく動かすことができないそうです。***

ここで、PC に Micro USB ケーブルを接続し、さらに Pro Micro を接続します。

elephant42_via.hex の下のほうにある `FLASH` をクリックします。ファームウェアの書き込み方法についての説明画面がでるので、その説明通りさらに `FLASH` をクリックします。

`remap-keys.app がシリアルポートへの接続を要求しています` という選択画面がでてくるので、RST と GND を一瞬ショートさせて Pro Micro を書き込み待機状態とさせます。
すると先ほどの選択画面に `Arduino Micro` という項目が出現するので、それを選択して接続ボタンをクリックします。

選択画面が消え、元の画面で処理が続行されます。最後に `Writing the firmware finished successfully.` とメッセージがでたら成功！ `CLOSE` をクリックして書き込みを終了します。

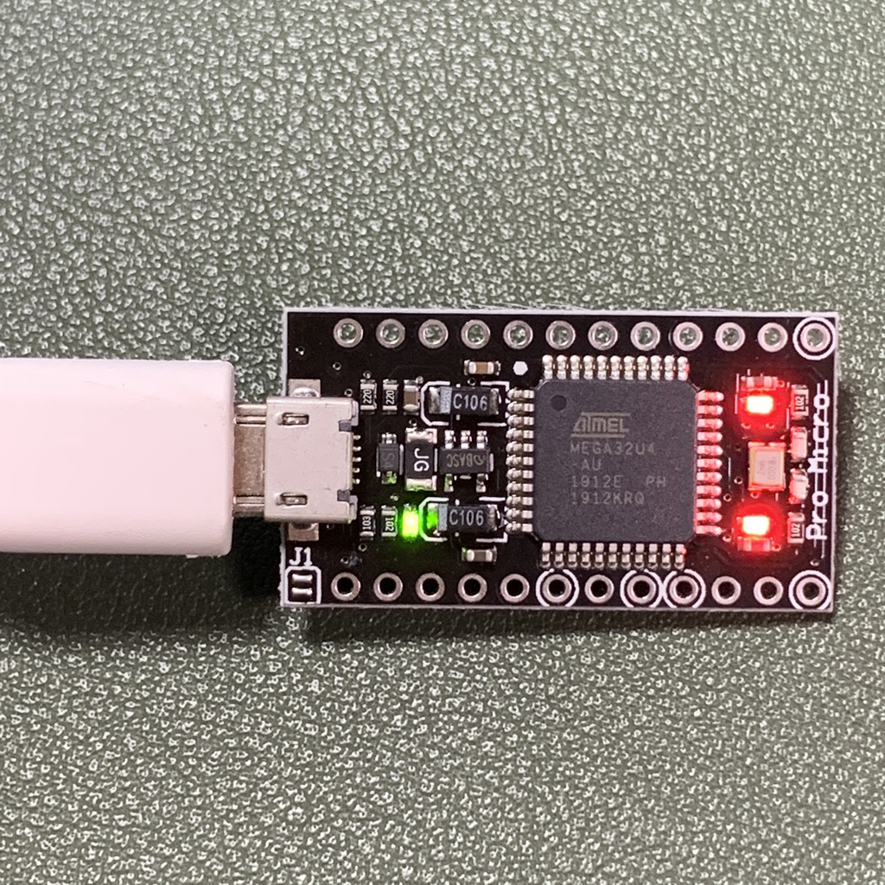
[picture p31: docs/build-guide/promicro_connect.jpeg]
connect
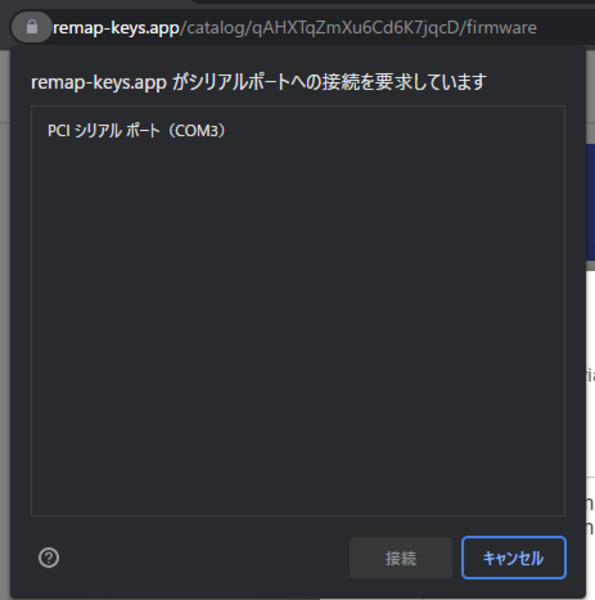
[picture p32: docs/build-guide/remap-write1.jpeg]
remap
|  |  |
|--|--|
| PC に ProMicro を接続する | `FLASH`すると、選択画面がでてくる |
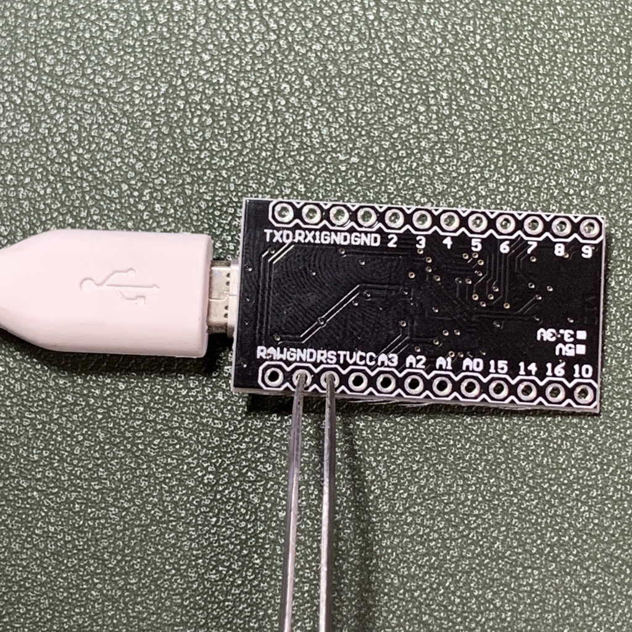
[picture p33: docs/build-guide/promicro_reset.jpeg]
firmware
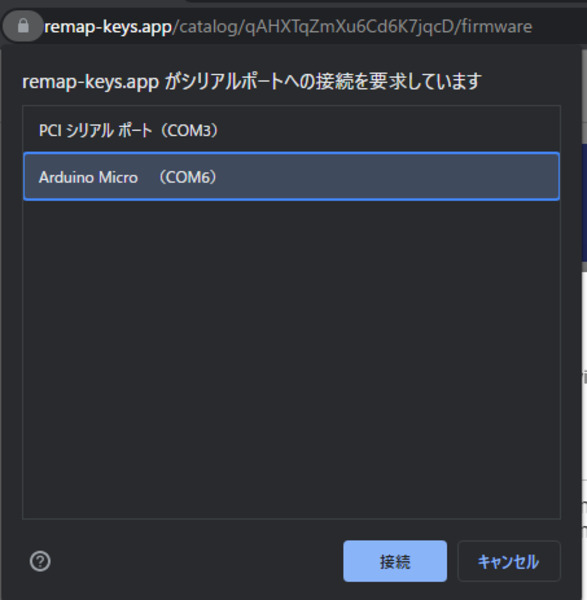
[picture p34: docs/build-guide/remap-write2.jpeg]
remap
|  | |
| RST と GND を一瞬ショートさせて書き込み待機モードにする | 選択画面に、`Arduino Micro` がでてくるので、それを選択して接続 |

これを左右両方ぶんの Pro Micro 2 つに対して実施します。完了したら、Remap との接続確認をしましょう。

[Remapのトップページ(https://remap-keys.app/)](https://remap-keys.app/) に飛び、`START REMAP FOR YOUR KEYBOARD` をクリックします。

さらに `+ KEYBOARD` をクリックすると、キーボードの接続ウィンドウがでます。そこで `elephant42` が出れば成功です！選択し、接続すると elephant42 のキーマップを編集したり、
LED の光りかたをいじったりできるのですが、今は Pro Micro に何もつながっていないので弄りようがありません。

USB ケーブルを抜くと元の画面に戻るので、両方の Pro Micro が正しくファームウェアを書き込めているか確認します。

うまくいかないときは、これまでの工程を注意深く確認しながらやり直してみてください。

## OLEDを使用する場合 (あるいは、こだわり派/分かってる人向け情報)

OLED を使用する場合、また Remap(VIA) 版で対応していない機能 (主にQMKの最新機能など) を使いたい場合は、
非常に残念ながら Pro Micro の容量の問題から 上記の方法ではうまくいきません。
自分で QMK Firmware のソースコードをビルドし、Pro Micro に書き込む必要があります。

**また、この方法で書き込まれたファームウェアは、Remap からキーマップの変更やLEDの操作ができません。基本的にすべてソースコードを弄ってはビルドし直す、という手順となります。**

プログラミング経験がある方なら難なくできる程度、そうでなくてもドキュメントは揃っているので頑張ってみれば案外どうにかなっちゃう程度の難易度ですが、
**黒い画面に白い文字で英語がズラっと並ぶ、よく映画でハッカーとかが見てるみたいな画面を見るハメになる** ので自信がない人は OLED を諦めたほうがいいかもしれません。

ただ、個人的には **OLED すごく力作だし、ちょっと前の自作キーボード界隈では誰もが普通にやっていた事ですし、なにより上手くいったときの喜びはひとしおですので、
食わず嫌いせずぜひトライしてみて欲しい** です。
私に連絡いただければ出来る限るのサポートもさせていただきますよ!!

ということで、まずはファームウェアのビルド環境を整えます。

https://docs.qmk.fm/#/ja/newbs_getting_started

をよく読み、お使いのPCに環境を構築します。

うまくいったら、`https://github.com/illness072/elephant42-firmware/releases` にあるソースコードをダウンロード&展開し、
QMK がダウンロードされたディレクトリの `keyboards/` の下に `elephant42` というディレクトリを作成して、そこに中身をコピーします。

つまり、 `<QMKの場所>/keyboards/elephant42/` に `README.md` や `elephant42.c` があるようになります。

git を使える人は、上記リポジトリを `keyboards/elephant42` 以下で git clone すると以降で更新がラクになります。

最後に `qmk` コマンドでビルド&書き込みします。

```
$ qmk flash -kb elephant42 -km default
```

とすると書き込みが実行されます。処理が進み、実際の書き込みを行う準備が整うと

```
Waiting for USB serial port - reset your controller now (Ctrl+C to cancel).....
```

と表示されるので、接続している ProMicro の RST と GND の両方を同時に一瞬だけピンセットなどで触れてショートさせます。

すると、Pro Micro のパワーランプが点滅し、実際の書き込みが開始されます。

最後に以下のような表示が出たら、書き込みは完了です。

```
avrdude done.  Thank you.
```

これを左右 2 つぶんの Pro Micro 両方に対して実施してください。

| connect | firmware |
|--|--|
| PC に ProMicro を接続し、書き込みコマンドを起動します | 待機状態になったら、RST と GND を一瞬ショートさせて書き込み処理を実行します |

なお、一部の環境では、コマンド実行時に以下のようなメッセージが出ることがあります。このときはそのまま Enter を押してしばらく待ち、書き込みが失敗して終わるのを待ちます。

```
sh: /tmp/1: Permission denied
.override rw-r--r--  root/wheel for /tmp/1? (y/n [n])
```

このように `permission denied` という文字列がでてエラーとなる場合は、

```
sudo qmk flash -kb elephant42 -km default
```

と書き換えて実行することで成功することができるかと思います。(パスワード入力を求められると思うので、アカウントのパスワードを入力してください。このとき画面には `****` だとか `●●●●` だとかは一切表示されませんが、それが普通なので気にせずパスワードを入力してEnterを押してください。)

# ハードウェアの組み立て

お待たせしました! いよいよハードウェアの組み立てです!!

## メイン基板 (PCB) の分割

PCB を 2 つに分割します。ミシン目に沿ってカッターで切り込みを入れ、手でゆっくり力をかけて折りとり、棒やすりで断面を整えます。

**カッターで基板の他の部分を傷つけないよう注意してください。**
**基板を折るさい、他の部分が折れたり曲がったりしないよう対象箇所のすぐそばを持って力を加えてください。**

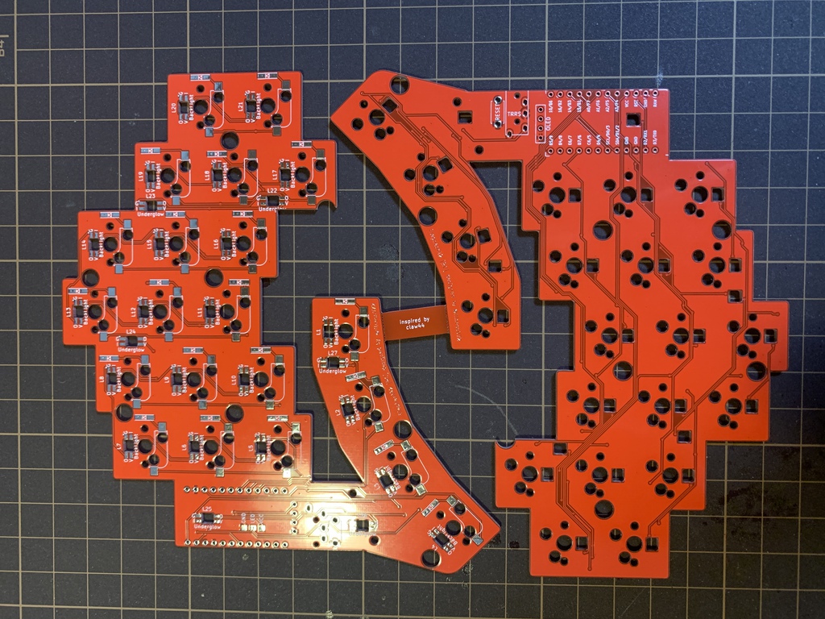
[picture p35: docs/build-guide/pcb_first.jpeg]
初期状態
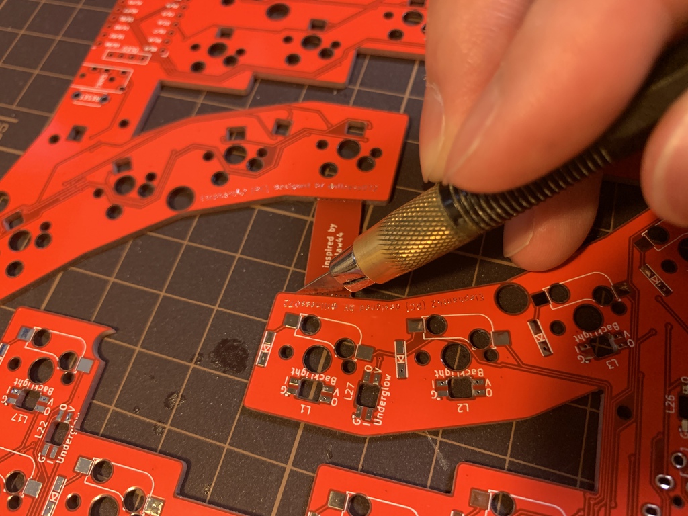
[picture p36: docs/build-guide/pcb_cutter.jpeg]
切り込みを入れる
|  |  |
|:--:|:--:|
| PCB を取り出し、カッターマットの上に置きます | ミシン目に沿って、カッターで切り込みを入れます。<br/>他の部分に傷をつけないよう、弱めの力で何十回も刃を当てます。 |
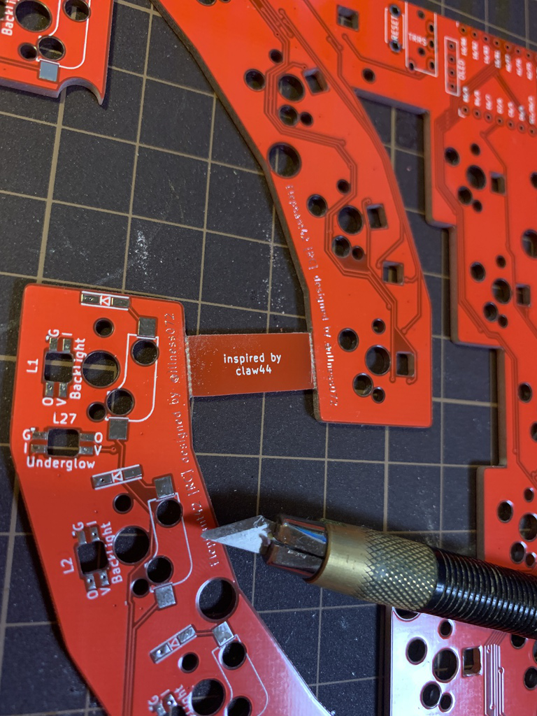
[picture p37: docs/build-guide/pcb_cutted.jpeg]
切り込みを入れた
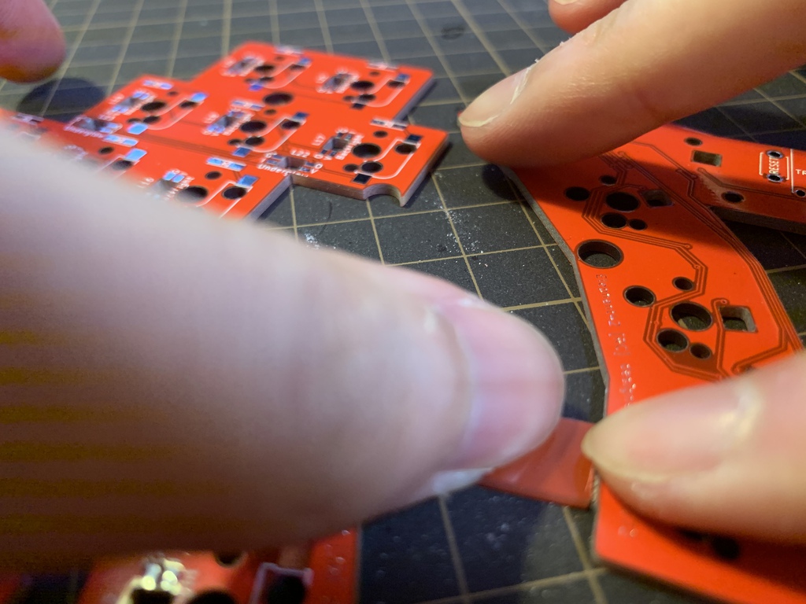
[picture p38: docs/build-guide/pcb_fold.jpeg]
折る
|  |  |
| 両サイド両面、ぜんぶで4箇所に切り込みを入れおわりました。 | 他の部分が折れたり曲がったりしないよう注意して折ります。<br/>固いようなら無理して折りとろうとせず、さらにカッターで深く切り込みを入れ直してください。 |
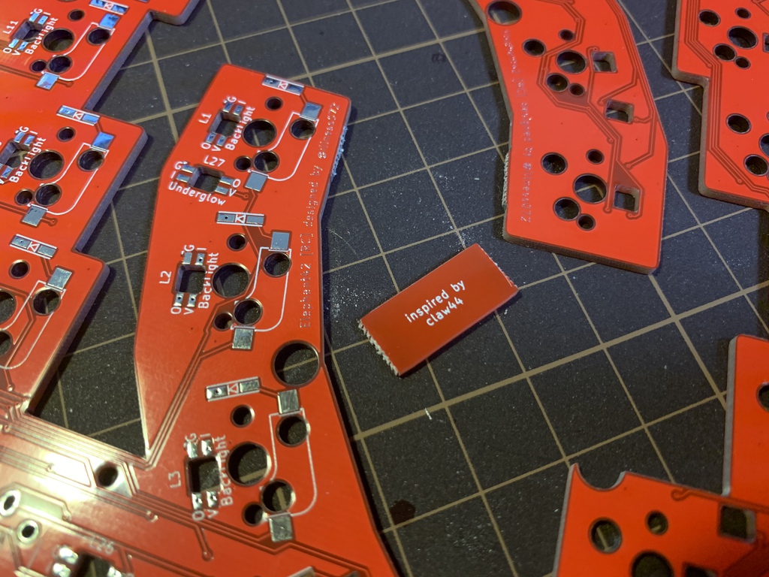
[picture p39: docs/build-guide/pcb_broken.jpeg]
折れた
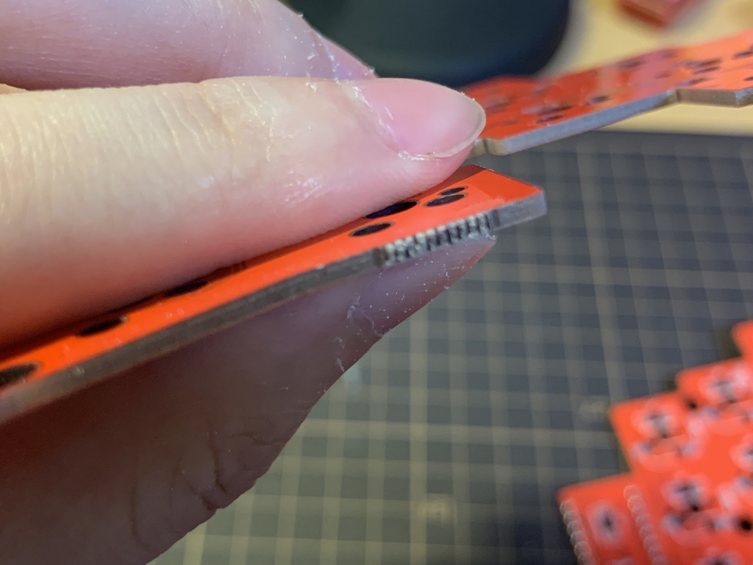
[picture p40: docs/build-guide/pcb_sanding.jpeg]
やすりがけ
|  |  |
| 両サイドとも無事綺麗に折れました。真ん中の小さな破片は不要なので捨てます。 | 折り取った面はギザギザで危ないので、棒やすりで綺麗にします。<br/>やすりがけ作業は粉が飛び散るので、掃除しやすい場所で汚れても良い格好で行うことをおすすめします。 |
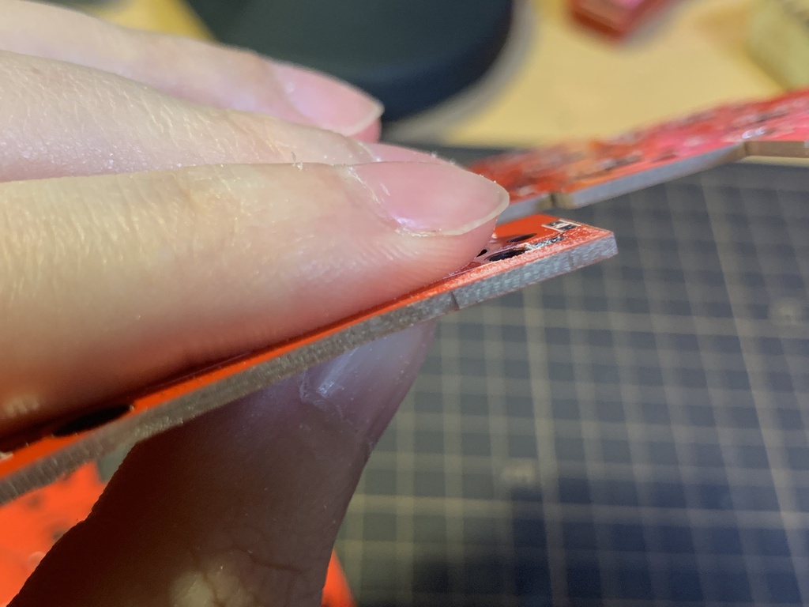
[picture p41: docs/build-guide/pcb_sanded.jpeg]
やすった
|  |
| 綺麗になりました。周囲を指でなぞって真っ平らになっていれば、微妙に縦線が入って見えていても大丈夫です。 |

### (オプション) PCB 側面の色塗り

写真の通り、 PCB 側面はなんか変な色で見栄えが悪く、また完成後もよく見えてしまうので色を塗ってしまうことをおすすめします。

油性ペンで側面をなぞり、表面や裏面についてしまったインクはティッシュやキムワイプで拭き取ります。

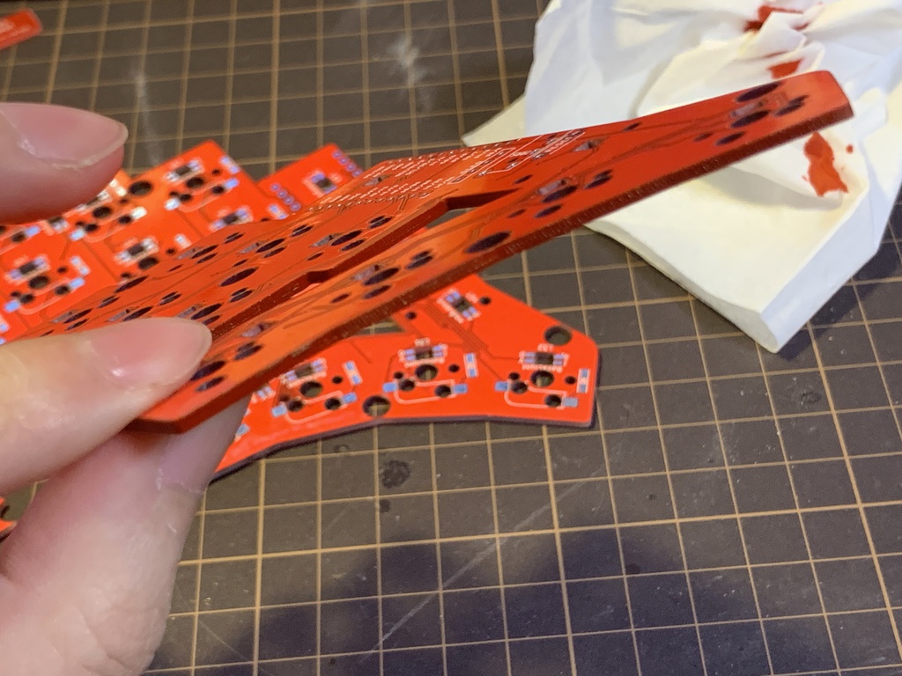
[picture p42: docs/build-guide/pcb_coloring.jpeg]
色を塗る
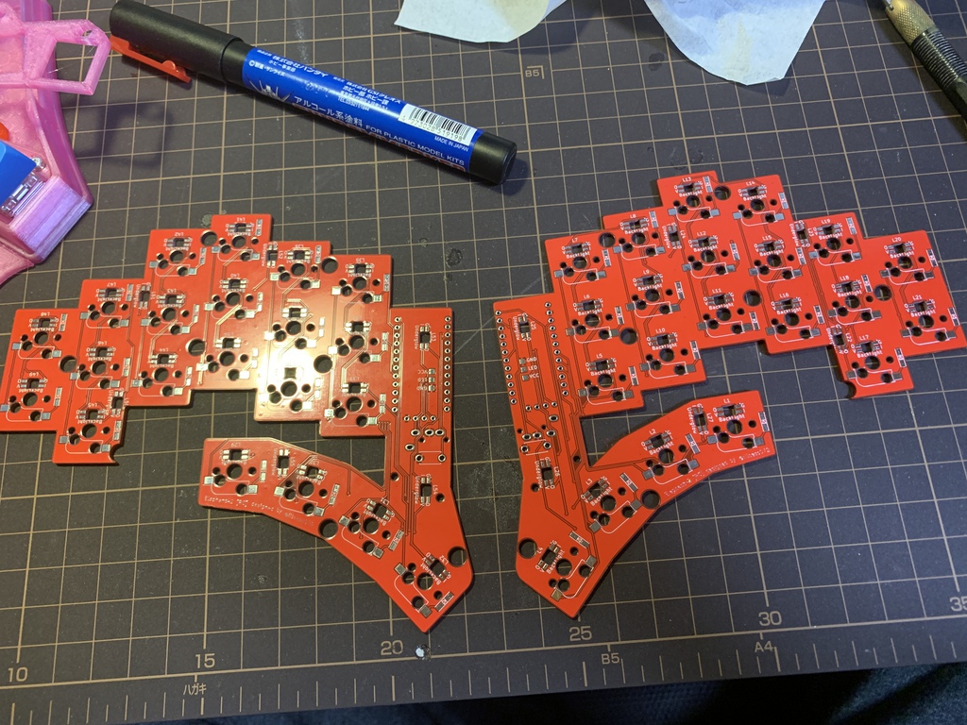
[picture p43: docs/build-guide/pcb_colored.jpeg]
乾かす
|  |  |
|:--:|:--:|
| PCB側面をペンで塗ります。はみだしたらすぐに拭き取ります | その後すぐに作業をすると手が汚れるので、乾かします。 |

PCB と同じ色で塗るのが一般的ですが、あえて異なる色で塗ってアクセントとするような作例もまた素敵ですよ! また、Pro Micro も同じように側面を塗るとより完成度が高まります。

## Pro Micro とコンスルーのはんだ付け

コンスルーの向きを確認し、写真を参考にして Pro Micro に嵌め込みます。

ProMicro とコンスルーが直角に取り付けられるよう、メイン基板 (PCB) にも嵌め込んだうえでコンスルーと ProMicro をはんだ付けします。

**はんだ付けするのは ProMicro とコンスルーで、メイン基板 (PCB) とコンスルーははんだ付けしません。**

ProMicro とコンスルーのはんだ付けが済んだら、ProMicro(とコンスルーをはんだ付けしたもの) は一度メイン基板から取り外しておきます。

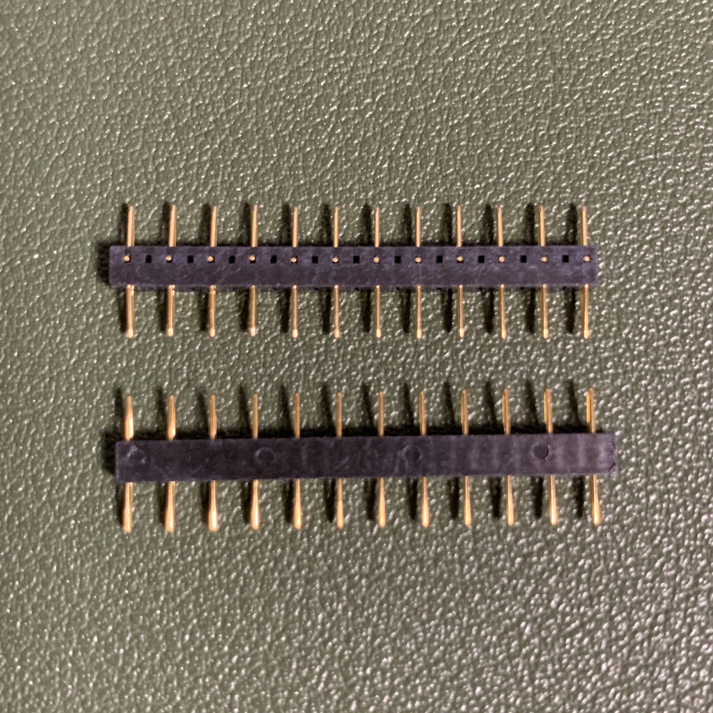
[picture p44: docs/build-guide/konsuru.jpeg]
コンスルー
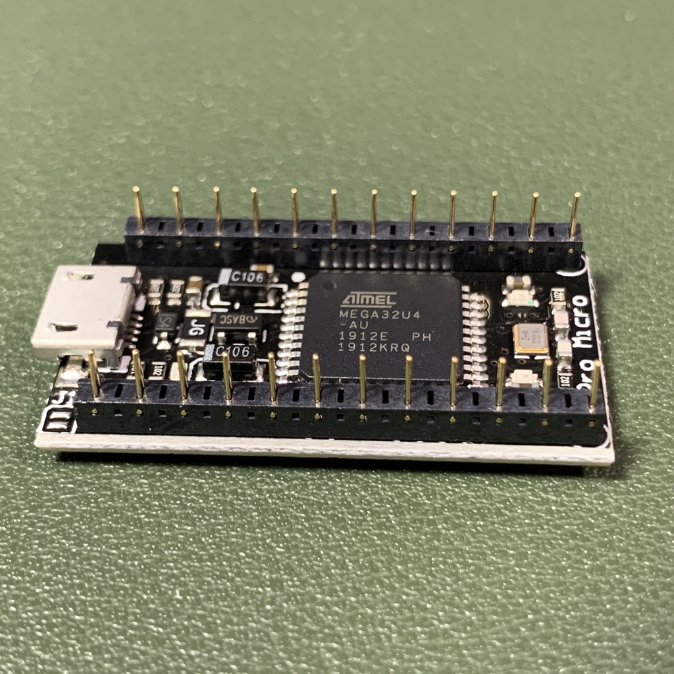
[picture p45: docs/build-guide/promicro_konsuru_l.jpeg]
プロマイクロに挿す
|  |  |
|:--:|:--:|
| コンスルーには向き(窓があいてる/あいてない)があります。 | コンスルーの向きを揃えて、 ProMicro のチップが見える側の面に挿します。 |
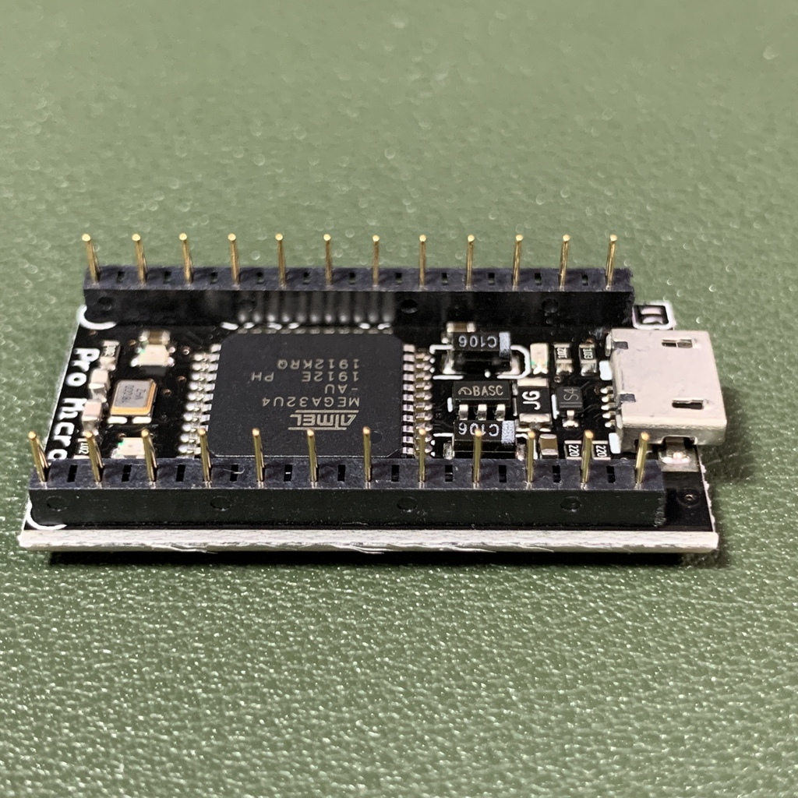
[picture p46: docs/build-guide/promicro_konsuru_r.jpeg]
反対側
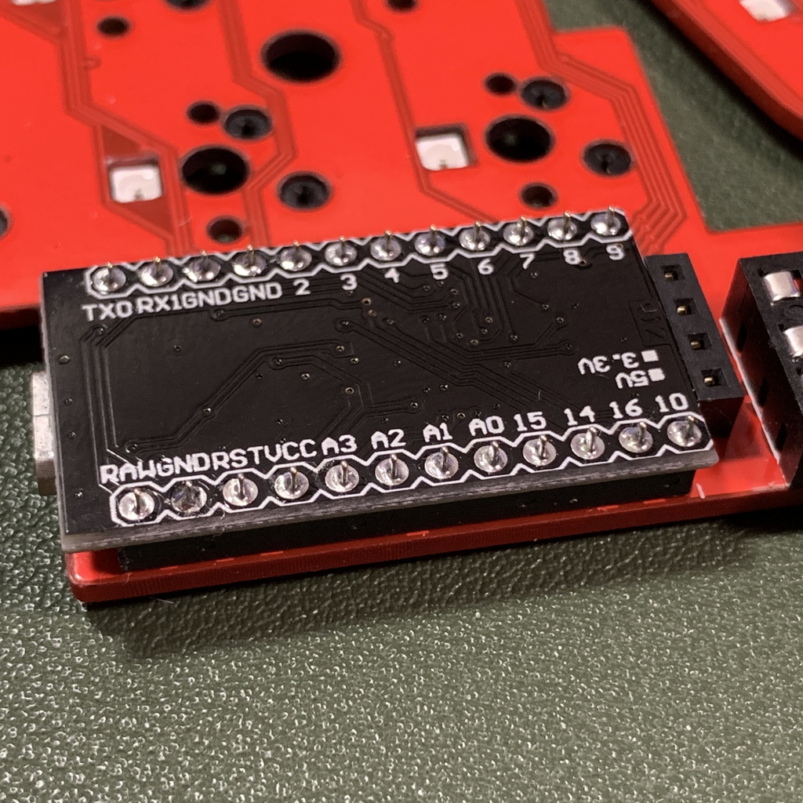
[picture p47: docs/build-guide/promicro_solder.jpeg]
はんだ付け
|  |  |
| 反対から見た図。コンスルーの向きが揃っているのを確認します。 | メイン基板 (PCB) に嵌めたうえで、各ピンを上からはんだ付けします。<br/>(写真を撮り忘れて後から撮影したので、ProMicro 以外のものも取り付けられていますが見なかったことにしてください。) |

なお、Pro Micro 上部からはみ出たコンスルーの足は切らないことをおすすめします。はんだ部が割れたり(クラック)、反対側から足がすっぽ抜けたりした事がありました。

## (オプション) バックライト/アンダーグロウ LED の取り付け

フルカラー LED の取り付けといえば自作キーボード界では最難関の一つとされる作業ですが、新型 LED の登場によりこれまでより格段にラクで安全に取り付けができるようになりました。

以前に挫折した経験のあるかたも、今回あらためて挑戦してみてはいかがでしょう？

### LED の動作確認方法

LED 取り付けば 1 個から数個とりつけるたびに動作確認をしていくとスムーズです。

すべての LED が同時に 「赤→緑→青→赤→...」と順番に点灯する `RGB Test` モードで LED を光らせることにより、はんだ付けした LED が無事に動いてるかどうかを確認できます。

Remap に接続し、elephant42 設定画面の右側、Lighting(太陽みたいなアイコン) をクリックして LED の操作画面を開きます。 `Effect Mode` を `RGB Test` にします。

消灯したい場合は `All Off` にすると消えます。

**良いかんじに取り付け＆テストが進んでいる様子**

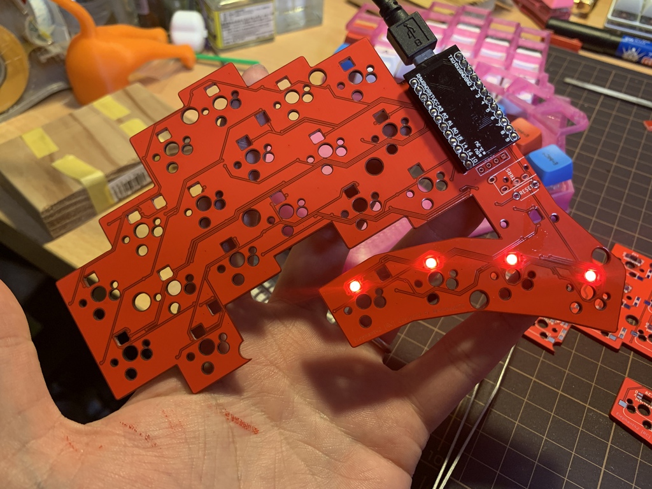
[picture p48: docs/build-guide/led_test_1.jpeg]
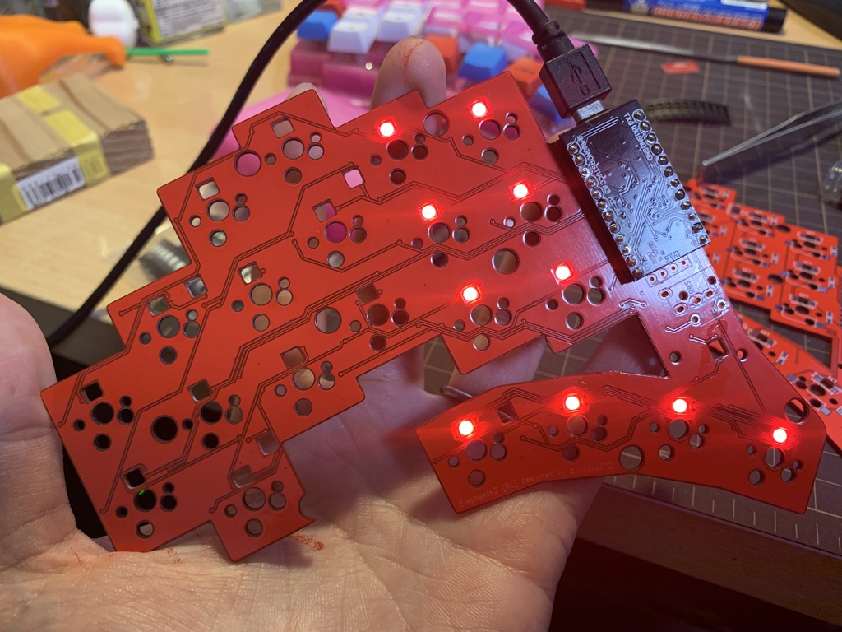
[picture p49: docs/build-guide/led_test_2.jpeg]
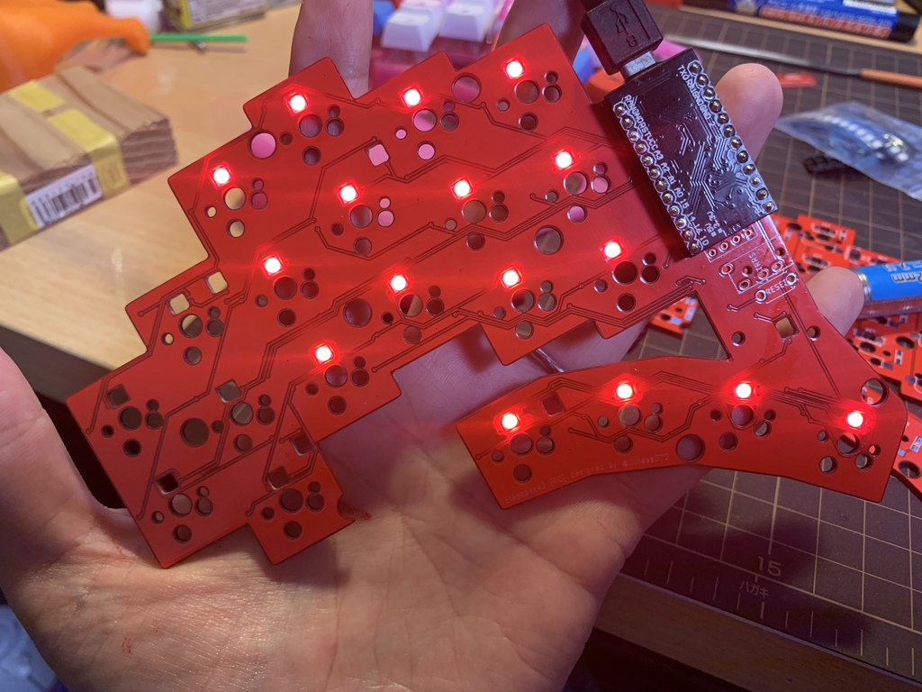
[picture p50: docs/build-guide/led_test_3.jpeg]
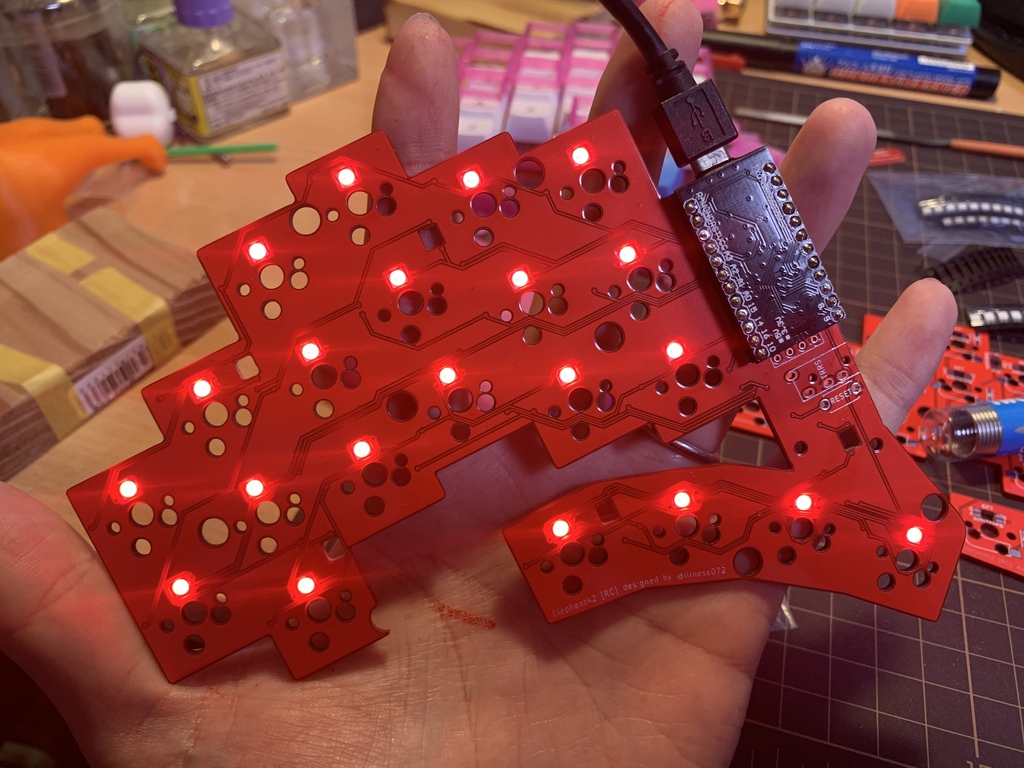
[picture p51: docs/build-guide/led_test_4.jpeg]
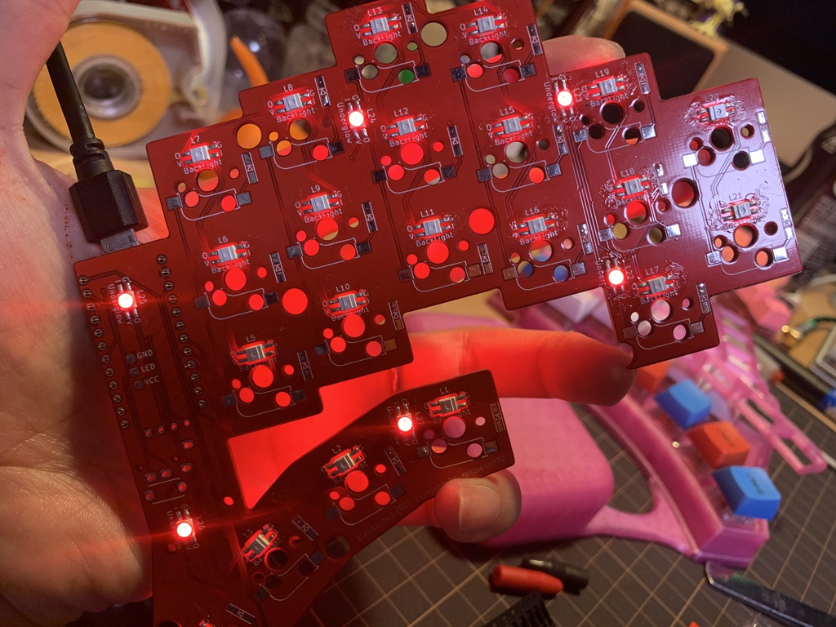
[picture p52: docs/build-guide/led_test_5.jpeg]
|  |  |  |  |  |
|:--:|:--:|:--:|:--:|:--:|
|親指のバックライトが光りました|人差し指も光りました|続いて中指と薬指。もうちょっと!|小指も完了。これでバックライトは完了!|アンダーグラウンドもOK。<br/>片手ぶんすべて完了!!|

また OLED を使用する場合など、Remap(VIA) 対応ファームを使用しない場合でも、一時的に Remap(VIA) 対応ファームを焼いて 上記通りに確認するのが一番てっとり早いです。
後の工程で実施するキーマトリクスの動作確認まで含めて Remap(VIA) 対応ファームで実施することをおすすめしています。

### バックライト LED の取り付け

まずはバックライト LED (左手:L1〜L21、右手: L29〜L49) だけ取り付けてしまいます。左右 21 個ずつ、計 42 個取り付けます。

はんだ付けにはフラックスを使用すると簡単・綺麗に、かつしっかりと接着させることができます。

LED は非常に小さいパーツなので、ぶち撒けて悲しい気持ちにならないよう少しずつ取り出して取り付けると良いです。

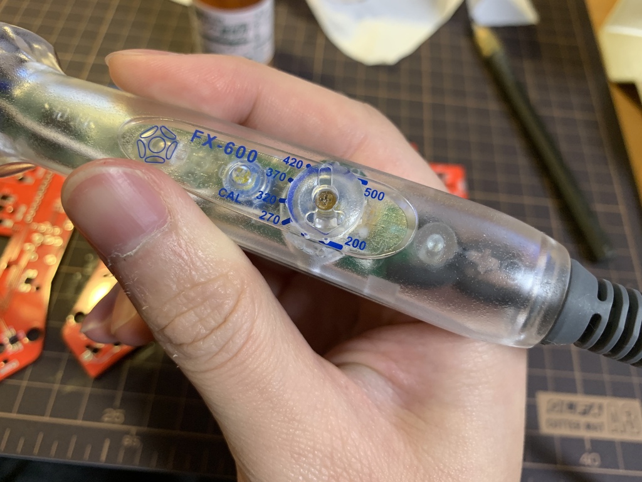
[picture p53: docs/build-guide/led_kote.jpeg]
こて温度設定
|  | 置く |
|:--:|:--:|
| はんだごての温度を低めに設定すると LED を焼き切ってしまう可能性が格段に減ります。<br/>使用するはんだの融点を確認して、なるべく低温で作業してください。 | PCB は裏向き(銀色のパッドが上に来る) に置きます。 |
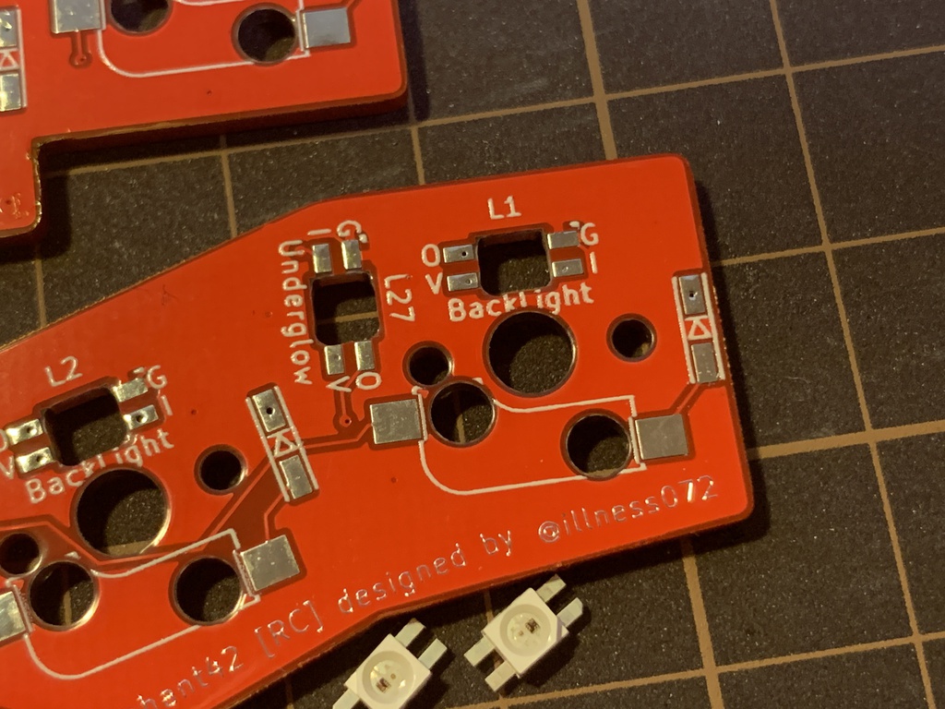
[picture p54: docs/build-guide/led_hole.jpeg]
LED取り付け穴
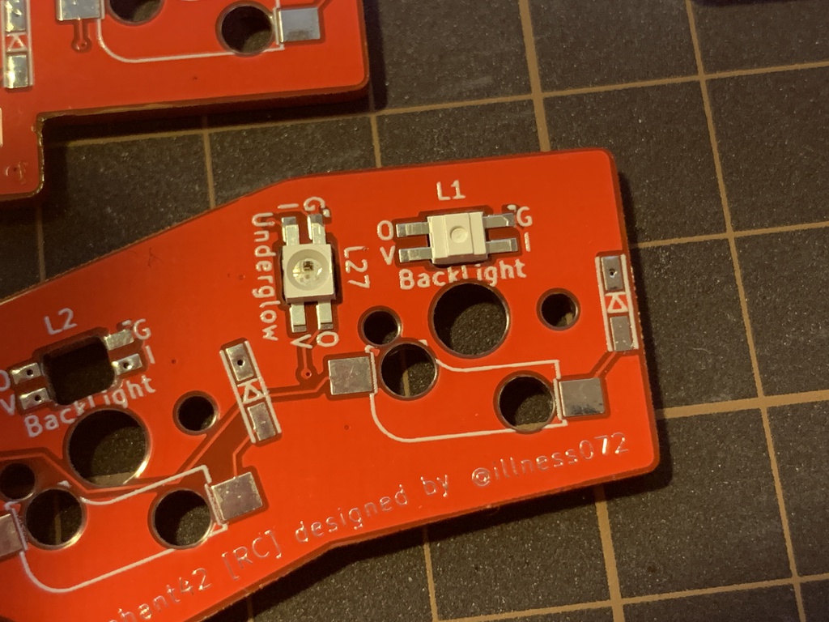
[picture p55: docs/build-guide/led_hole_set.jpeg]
LED配置例
|  |  |
| LED は白い文字(シルク)で Backlight あるいは Underglow と書かれた四角い穴に取り付けます。<br/>**L1, L2, ... と書かれた取り付け番号順に従って取り付けていってください。** | LED は向きがあります。Backlight は下向きに、Underglow は上向きに配置します。<br/>また LED から伸びた 4 本のタブのうち 1 つだけ切り欠きがあるので、そのタブが 'G' の位置に来るようにします。<br/>**向きが間違っているとLEDは点灯せず、最悪キーボード自体の故障にもつながります。細心の注意をはらって配置してください。** |
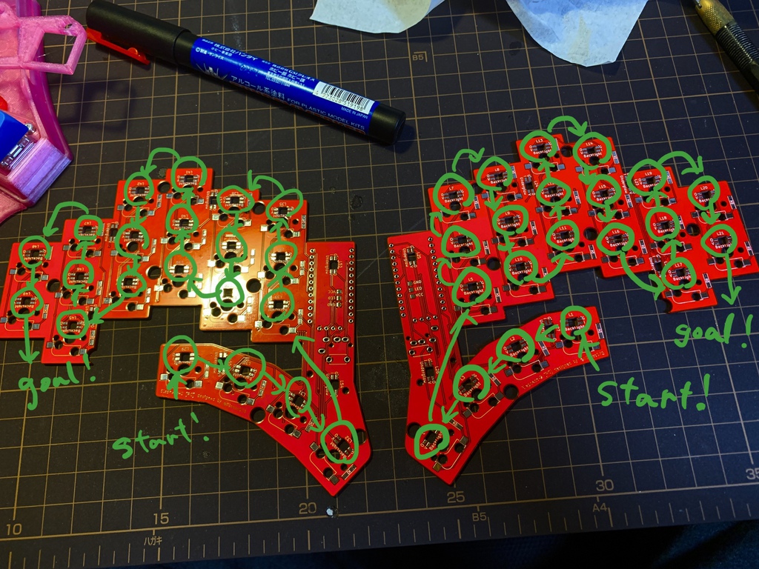
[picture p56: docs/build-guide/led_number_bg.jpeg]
バックライト取り付け順
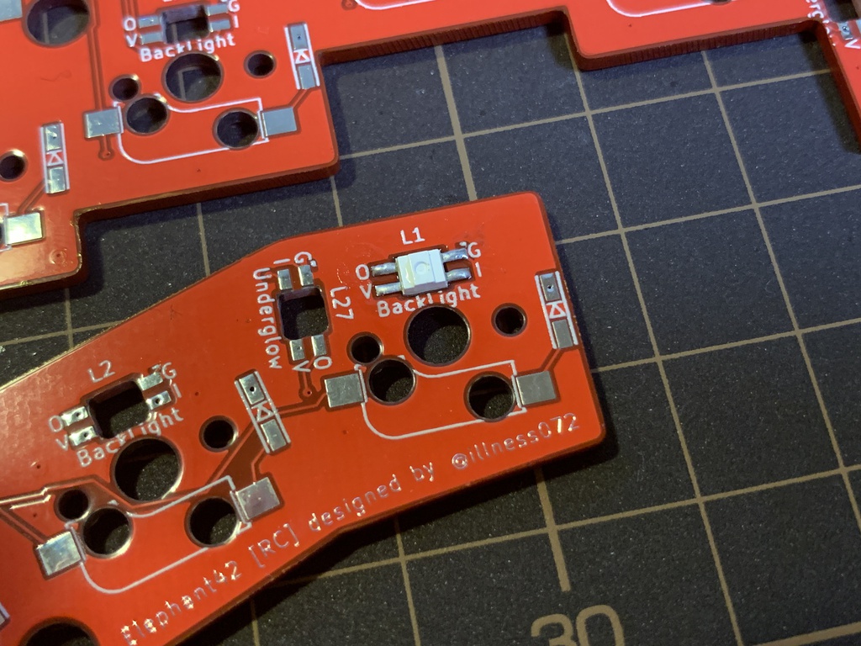
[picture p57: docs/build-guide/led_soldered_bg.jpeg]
バックライト取り付け例
|  |  |
| 図のように親指側から小指の順に、LED取り付け穴のそばにある白字の L1, L2 ... の記載(シルク)の番号順にそって取り付けます。 | L1 をはんだ付けしました。LEDのタブが基板から浮いていないか、しっかり目視確認してください。 |

### アンダーグロウ LED の取り付け

バックライト LED の取り付けが完了して、LED TEST もすべてパスしたらアンダーグロウ LED  (左手:L22〜L27、右手: L50〜L55) の取り付けに取り掛かります。左右 6 個ずつ、計 12 個取り付けます。

| アンダーグロウ取り付け順 | アンダーグロウ取り付け例 |
|:--:|:--:|
| 次はアンダーグロウです。バックライト同様、シルクの番号順に取り付けます。 | L27 を取り付けました。バックグラウンドとアンダーグロウは表裏が逆になるので注意してください。 |

### LED 取り付け トラブルシューティング

**取り付け穴がきつくて LED が嵌らない**

基板製造の製造誤差によりこうなってしまう場合があります。十分に検品しているつもりですが、抜けがあってすみません。

このような場合は無理に押し込まず、LED 穴の内側を棒やすりで少し削り、穴を広げてみてください。

**光らない LED がある**

その光らない LED か、その 1 つ前の LED がおかしい可能性が高いです。

elephant42 に使用されている SK6812MINI-E でなく、その改良前版の SK6812MINI についての記事ですが、
デバッグ方法がこちらの記事に詳しく書かれていますので、熟読されることをおすすめします。

[コルネキーボードを作りました ～LED取り付けに四苦八苦記～ | キオクノロンダリング](https://marksard.github.io/2018/08/04/make-the-crkbd/)

SK6812MINI-E のピンアサインは以下の通りなので、SK6812MINI のそれとは異なります。適宜読み替えてください。

| LED ピンアサイン(表) | LED ピンアサイン(裏) |
|:--:|:--:|
| LED ピンアサイン(表) | LED ピンアサイン(裏) |

**LED取り付け間違えちゃった!!**

LED の修正で大事な事は、**あわててすぐに取り外さないこと** です。

基本的に、LED自体が壊れるか、向きを間違っているかでなければ、上から温めなおしたり追いはんだをするだけで上手くいくことが多いです。

部品の取り外しを行うさいは、慎重かつ上手にやらないと基板にダメージが行きやすく、最悪ランドが剥れるなどの大惨事になりかねないので十二分に注意してください。

もし基板が破損してしまった場合は、基板単体販売も行っていますのでそちらをご利用ください。

## ダイオードの取り付け

ダイオードを左右 21 個ずつ、計 42 個取り付けます。**ダイオードは向きがあるので注意してください。**

ダイオードは非常に小さいパーツなので、ぶち撒けて暗い気持ちにならないよう少しずつ取り出して取り付けると良いです。

| ダイオード取り付け前 | ダイオード取り付け後 |
|:--:|:--:|
| `\|◁` マークのシルクがある箇所に取り付けます。 | `\|◁` の `\|` がある方にダイオードの縦線が向くように取り付けます。 |

## スイッチソケットの取り付け

スイッチソケットを左右 21 個ずつ、計 42 個取り付けます。**ソケットにも向きがあるので注意してください。**

スイッチソケットはさほど小さいパーツでもなく、ぶち撒けても言うほど辛い気持ちにはなりませんが、それでも一応少しずつ取り出して取り付けると良いです。

| ソケット取り付け前 | ソケット注意点 |
|:--:|:--:|
| ソケットを取り付けます。シルクの枠線通りに取り付けてください。 | 一部ダイオード取り付け位置とすごく近い所があるので気をつけて取り付けてください。 |

## TRRS ジャック、リセットスイッチの取り付け

TRRS ジャックおよび リセットスイッチをそれぞれ左右 1 つずつ取り付けます。

**PCBを裏返し、表側から嵌め込み、また裏返して裏側をはんだ付けします。**

TRRS ジャックは裏返したさいに落ちてしまうので、マスキングテープで固定しておくと良いです。

| 取り付け例 |
|:--:|
| 表側から TRRS ジャックとスイッチを嵌めこみ、裏側からはんだ付けをします。**表裏に注意してください。** |

PCB から飛び出る TRRS ジャックやリセットスイッチの足が長すぎると感じるときは、ニッパーなどで少し切ってあげると見栄えがよくなります。

## (オプション) OLED の取り付け

OLED を取り付ける場合は、OLED 付属のピンソケットを取り付けてください。

こちらも**表側から嵌め込み、裏側をはんだ付けします。**

ピンソケットは裏返したさいに落ちてしまうので、マスキングテープで固定しておくと良いです。

| 取り付け例 | 完了 |
|:--:|:--:|
| 表側からピンソケットを嵌めこみ、裏側からはんだ付けをします。**表裏に注意してください。** | ピンソケットにピンヘッダを挿し、さらに OLED を挿し、OLED とピンヘッダをはんだ付けします。 |

## 動作確認

ここまでではんだ付けの作業はすべて完了しました。これまでの作業が上手くできているかの確認をしましょう。

まず、ProMicro を取り付け、TRS ケーブルおよび USB ケーブルを接続します。**USBケーブルは左手側に挿すようにしてください。**

Remap に接続し、elephant42 設定画面の右下側、 … のアイコンをクリックしたメニューのなかから `Test Matrix mode` をクリックします。

Test Matrix mode では押されたキーが青く変化します。ぜんぶのキーについて動作確認(つまり表示されているキーがすべて青くなる)できれば完了です！

対象のキーについて一時的にソケットにキースイッチを刺して押してみるか、ピンセットでソケットの両端を触ることで確認をしていきます。

| ProMicroを取り付ける | スイッチソケットをショートする |
|:--:|:--:|
| 表側から ProMicro を取り付け、全てのケーブルを接続し、再度ファームウェアを焼きます。<br/>OLEDを取り付ける場合は、OLEDも取り付けますが、Remap(VIA)版ファームなのでこの時点では点灯しません。 | 任意のキーソケットをショートさせ、該当するキーが押されたように振る舞うかを確認する。**裏側から触っていることになるため、左右逆になります。** |
| 動作確認 | デフォルトキーマップ(右) |
| 各キーについて動作確認をしていきます・・・ | すべて青くなれば完了！　**おめでとう！！** |

### 動作確認 トラブルシューティング

**LEDが光らない**

デフォルトファームを焼いたばかりだと光らないはずなので、挙動としては正しいです。

Raise(右手側親指、内側から2番目を押しっぱなしにする) + c を押すと LED のオン/オフができます。

**特定のキーだけが反応しない**

キーソケットかダイオードのはんだ不良、ダイオードの向きが逆、などが考えられます

**特定のキーが意図してない文字を入力する**

どこかがショートしている可能性が高いです。しらみつぶしに確認してみてください

**特定の行すべて、特定の列すべてが反応しない**

Pro Micro の差し込み不良やコンスルーのはんだ不良が考えられます。

**両手とも全てのキーが反応しない**

特に左手の ProMicro が抜けかかっていないか、表裏逆に取り付けていないか確認してみてください。

**右手側(USBを挿してない方)だけ全てのキーが反応しない**

右手側の ProMicro が抜けかかっていないか、表裏逆に取り付けていないか確認してみてください。

あるいは、TRS ケーブルが奥まで挿さっていない場合や、不良品の場合も考えられます。

**左右逆の挙動をする**

まず、キーボードを裏側から見ていることに気をつけてください。

それでも逆である場合は、おそらく USB ケーブルを右手側(つまり左側)に挿しているのではないでしょうか。

**左右どちらも左手(または右手)の挙動をする**

あんまり良くわかってないですが、こうするとだいたいうまくいく事が多いです

1. TRS ケーブルを抜き、左右両方の elephant42 ファームの焼き直しをする
2. TRS ケーブルを挿し、左手だけ再度 elephant42 ファームの焼き直しをする
3. USB ケーブルを抜いてまた挿す

**デフォルトキーマップが Mac 用っぽいけど、使ってるの Windows なのですが。。。**

ごめんなさい、Windows 持ってなくて動作確認ができていません。
両 OS 間での違いは Opt が Alt 扱いになること、Cmd が Win キー扱いになることだけのはずです。

**それ以外、または上記解決策で解決しない**

私で解決できるか不安でしかないですが、とりあえず [私に連絡](https://twitter.com/illness072/) してきてください。できる限りのお手伝いをします。

がんばって幸せになりましょう!!

### (OLEDを使用する場合) OLED の動作確認

さて、OLEDファームウェアを書き込みし直して OLED が光るかを確認しましょう!!

右手側に elephant42 ロゴ、左手側にレイヤー表示とキー入力するたびにちょこちょこ動く 🐘 のアイコンが映れば OK!!

動かない場合はファームウェアの書き込み不良かはんだ不良が考えられます。再度確認しましょう!

### フラックスの洗浄

動作確認が済めば、はんだごての出番はもうおしまいです。フラックス洗浄剤を塗りたくりキムワイプで拭き取ってしまいましょう。

基板がピカピカになると最後の組み立てのテンションが段違いですよ!!

## ねじ留め

さぁ、完成も間近です。

アクリルプレートから保護紙を丁寧に剥がし、ホコリや指紋や汚れがつかないよう丁寧に組付けると美しく仕上がります。

| ProMicro 保護プレートの取り付け 1 | ProMicro 保護プレートの取り付け 2 |
|:--:|:--:|
| ProMicro 保護プレートにスペーサーをねじ留めします。<br/>OLED を取り付けている場合はスペーサー(長)を、取り付けていない場合はスペーサー(短)を使用してください。 | さらに ProMicro 保護プレート + スペーサーを基板にねじ留めします。 |
| トッププレートの取り付け | ミドルプレートの取り付け |
| トッププレートにスペーサー(短)をねじ留めします。<br/>**指紋がつかないよう注意!!** | その上からミドルプレートを乗せます。<br/>**ホコリを挟みこまないよう注意!!** |
| PCB の取り付け | ボトムプレートの取り付け |
| さらに PCB を乗せます。 | 最後にボトムプレートを乗せ、ねじ留めします。 |
| クッションゴムの取り付け | ねじ留め完了 |
| クッションゴムを貼りつけます。 | ひっくり返して、キーボード本体の完成です。 |
| キースイッチの取り付け | キーキャップの取り付け |
| あとはお好みのキースイッチを取りつけ・・・ | キーキャップをはめこめば、できあがり!! |

両手ぶん作成し、ケーブル類を繋げれば、貴方だけの elephant42 が目の前にあるはずです。おめでとう!!

## (オプション) 完成を喜ぶ

達成感に震え小踊りなどを済ませましたら、
できあがった elephant42 の写真を撮って Twitter にアップなどしてみてはいかがでしょうか？ (なお [`#elephant42`](https://twitter.com/hashtag/elephant42) ハッシュタグを付けてツイートしてくださると最高にうれしいです。ご意見や感想などもお気軽にお伝えください。)

# カスタマイズする

さて、キーボードは完成しましたがこれは始まりでしかありません。

自作キーボードの真の魅力は、無限のカスタマイズ性にあります。あなたのキーボードを、あなただけの最高のキーボードに仕上げていきましょう。

## キーマップのカスタマイズ

デフォルトキーマップではこうなってるけど、自分はこうしたいんだよなぁ。みたいな風に思うこともあるのではないでしょうか？

Remap に接続し、あなただけのキーマップを作り込んでいきましょう!!

### Remap を使用しない場合

これらのドキュメントを参考に、キーマップを好きにカスタマイズすることができます。

[初めてのファームウェアを構築する](https://docs.qmk.fm/#/ja/newbs_building_firmware)
[はじめてのQMKキーマップ編集](https://qiita.com/marksard/items/9317949ce1da327f7436)

## OLED のカスタマイズ

OLED つけたはいいけど、なんかダサいな。とお嘆きのあなた。好きな画像を表示させることもできます。

やりかたは色々ありますが、私はこのサービスを使わせてもらっています。(Helix専用のようなタイトルですが elephant42 でも問題なく使用することができます)

[HelixのOLED表示を簡単にカスタマイズするサービスを作った](https://qiita.com/guri3/items/844675b637c88515a989)

作成されたファイルを、QMK の keyboards/elephant42/keymaps/default/glcdfont.c と差し替えてファームウェアのビルド・書き込みを行うことで OLED の表示を変えることができます。

## アクリルプレートのカスタマイズ

elephant42 は「蛍光エッジ ピンク」というアクリルプレートを使用していますが、なにも絶対にピンクを使わなければならないわけではありません。

[プレートのカットデータ](https://github.com/illness072/elephant42/tree/master/plates) を用いて、アクリルカットサービスを利用して好きな色の elephant42 を作ることができます。

- [レーザー加工サービス | 遊舎工房](https://yushakobo.jp/shop/lasercut/)

## 専用ケースの 3D プリント

elephant42 専用の [光るパームレスト一体型ケース](https://github.com/illness072/elephant42/tree/master/cases/) もあわせて開発中です。

ご自宅の 3Dプリンタや各種 3Dプリントサービスで出力してみてください。

また、[プレートのカットデータ](https://github.com/illness072/elephant42/tree/master/plates) も公開していますので、完全オリジナルのケース設計にも挑戦しやすくなっているかと思います。(作ったらぜひ見せてください!!)

# 日々のお手入れ

## 掃除

elephant42 はアクリルプレートを素材に使用する都合上、手脂などによる指紋の付着や、静電気によるホコリの付着がどうしても起こりやすくなっています。

気になる場合はプラスチック/アクリル樹脂用の静電気防止機能つきクリーナー材による定期的な分解清掃をお勧めします。

私は 「アクリサンデー 静電気防止クリーナー ポリケアF70」 というものをよく使っています。

## ファームウェアアップデート

問題なく動作しているのであれば、実際定期的なファームウェアアップデートはあまり必要ないですが、QMK の新機能を試したい時などはやってみるのも良いかもしれません。

また、 elephant42 のファームウェアとしても、たまに気分次第でアップデートをかけています。興味のある方はぜひ。

# さいごに

本ビルドガイドを書くにあたり、なる(@nrtkbb) さんの [uzu42ビルドガイド](https://github.com/nrtkbb/Keyboards/blob/master/uzu42/build_guide_jp.md) を大変参考にさせていただきました。ほんとうにありがとうございました。

elephant42 は、ふく(@yfuku_) さんの [claw44](https://booth.pm/ja/items/1283873) の設計思想に非常に強く影響を受けたキーボードです。すごく良いキーボードですので、良かったらそちらも試してみてください。

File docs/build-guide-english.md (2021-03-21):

# How to assemble an elephant42

This is the build guide (assembly manual) for the self-made keyboard kit [elephant42](https://illness072.booth.pm/items/1775017).

**Before assembling, please read and understand this build guide first, prepare materials, tools, etc., build the environment, and finally perform the actual assembly work.**

**If you don't understand something or it doesn't work, don't be disappointed and give up there. Try [contacting me](https://twitter.com/illness072/). I would like to make an effort to help as much as possible.**

It will be smooth if you can ask "what you are trying to do", "what you did", and "what is going on" in an easy-to-understand manner.

<!-- START doctoc generated TOC please keep comment here to allow auto update -->
<!-- DON'T EDIT THIS SECTION, INSTEAD RE-RUN doctoc TO UPDATE -->

- [How to assemble an elephant42](#how-to-assemble-an-elephant42)
- [Preparation](#preparation)
  - [Check the contents of the kit](#check-the-contents-of-the-kit)
  - [Procurement of necessary parts](#procurement-of-necessary-parts)
    - [Required](#required)
    - [Optional](#optional)
  - [Tool Preparations](#tool-preparations)
    - [Necessary Things](#necessary-things)
    - [Good Things to Have](#good-things-to-have)
    - [Useful for Shopping](#useful-for-shopping)
  - [(For beginners) Studying soldering](#for-beginners-studying-soldering)
  - [Confirmation of the entire assembly process](#confirmation-of-the-entire-assembly-process)
  - [QMK firmware Build environment](#qmk-firmware-build-environment)
    - [QMK Environment Construction Troubleshooting](#qmk-environment-construction-troubleshooting)
  - [Pro Micro's measures against baldness](#pro-micros-measures-against-baldness)
- [Assembly work](#assembly-work)
  - [(Optional) Enable OLED option in firmware](#optional-enable-oled-option-in-firmware)
  - [Writing QMK firmware](#writing-qmk-firmware)
    - [QMK Write Troubleshooting](#qmk-write-troubleshooting)
  - [Main board (PCB) partition](#main-board-pcb-partition)
    - [(Optional) Color the sides of the PCB](#optional-color-the-sides-of-the-pcb)
  - [Soldering Pro Micro and Conthru](#soldering-pro-micro-and-conthru)
  - [(Optional) Backlight / Underglow LED installation](#optional-backlight--underglow-led-installation)
    - [Installation of backlight LED](#installation-of-backlight-led)
    - [LED TEST method](#led-test-method)
    - [Installation of underglow LED](#installation-of-underglow-led)
    - [LED installation troubleshooting](#led-installation-troubleshooting)
  - [Installation of diode](#installation-of-diode)
  - [Installing the switch socket](#installing-the-switch-socket)
  - [Installation of TRRS jack and reset switch](#installation-of-trrs-jack-and-reset-switch)
  - [(Optional) OLED installation](#optional-oled-installation)
    - [Please note only the RC version](#please-note-only-the-rc-version)
  - [Operation check](#operation-check)
    - [Operation check Troubleshooting](#operation-check-troubleshooting)
    - [Flux Cleaning](#flux-cleaning)
  - [Screwed](#screwed)
  - [(Optional) Rejoice in completion](#optional-rejoice-in-completion)
- [Customize](#customize)
  - [Keymap customization](#keymap-customization)
  - [OLED customization](#oled-customization)
  - [Acrylic plate customization](#acrylic-plate-customization)
  - [3D printing of special case](#3d-printing-of-special-case)
- [Daily care](#daily-care)
  - [clean up](#clean-up)
  - [Firmware update](#firmware-update)
- [finally](#finally)

<!-- END doctoc generated TOC please keep comment here to allow auto update -->

# Preparation

## Check the contents of the kit

Check that the contents are not missing or damaged.

Each acrylic plate has protective paper on the front and back. You can peel it off immediately, but it is better not to peel it off until just before assembly so that it will not get fingerprints, dust or dirt.

| Board (PCB) |Top plate |Middle plate |Bottom plate |
|:-: |:-: |:-: |:-: |
| Main board (PCB) ... 1 sheet <br />*** 1**| Top plate ... 2 sheets <br /> (Thinner with smaller holes) | Middle plate ... 2 sheets < br /> (Thicker and larger hole) | Bottom plate ... 2 sheets |
|ProMicro Protective Plate |Diode |PCC Socket for MX Compatible Switch |TRRS Jack |
| ProMicro protective plate ... 2 pieces <br />*** 2**| Diodes ... 44 pieces <br /> (2 spare pieces) | For MX compatible switches <br /> PCB sockets ... 42 Pieces | TRRS Jack ... 2 pieces |
|Tact switch |Spacer (short) |Spacer (long) |Screw |
| Tact switch ... 2 pieces <br /> * Colors may vary | Spacer (short) ... 20 pieces | Spacer (long) ... 4 pieces | Screws ... 40 pieces |
|Cushion rubber ||||
| Cushion rubber ... 10 pieces ||||

* 1 ... From v1, the board color is white. There is no difference in how to assemble.

* 2 ... ProMicro protective plates include two 2mm thick ones with the elephant42 logo engraved and two 3mm thick ones, for a total of four. Please select according to your preference.

## Procurement of necessary parts

Buy what you need but not included in the kit.

Please refer to the link of the recommended purchase destination (domestic mail order) for beginners.

### Required

- **Pro Micro (with conthrough) ... 2 pairs**
   - Recommended purchase destination
     - [Pro Micro (with conthrough) | Yusha Kobo](https://yushakobo.jp/shop/promicro-spring-pinheader/) * Please purchase two
     - TALP KEYBOARD
       - [Pro Micro ATmega32U4 5V/16MHz/MicroUSB2 (compatible product)](https://talpkeyboard.stores.jp/items/5b24504ba6e6ee7ec60063e3) * Please purchase two
       - [MAC8 Conthru XB-3-2.5-12P (Height 2.5mm/12 pins/1 piece)](https://talpkeyboard.stores.jp/items/5e056626d790db16e2889233) * Please purchase 4
     - Very cheap Pro Micro is sold as a set on Amazon etc., but it is safer to buy it at a proper store because you will get a bad product with a good probability.
   - Many domestic kits are included, but this kit is not included.
- MX compatible switches ... 42
   - Recommended purchase destination
     - [Switches | Yusha Kobo](https://yushakobo.jp/product-category/switches/)
     - [TALP KEYBOARD](https://talpkeyboard.stores.jp/?category_id=59cf8860ed05e668db003f5d)
     - [SWITCHES --Yukari Keyboard Factory](https://eucalyn.shop/product-category/keyswitches)
   --Please note that "Kailh Low Profile (Choc) Switch" and "Kailh Mid-Height Switch" are not supported.
- 1U keycap ... 42 pieces
   - Recommended purchase destination
     - [Keycaps | Yusha Kobo](https://yushakobo.jp/product-category/keycaps/)
     - [TALP KEYBOARD](https://talpkeyboard.stores.jp/?category_id=59be183f428f2d49120007b1)
     - [KEYCAPS --Yukari Keyboard Factory](https://eucalyn.shop/product-category/keycaps)
     - [Tai-Hao shop](https://shop.tai-hao.com/) * Overseas
     - [Rice keycap self-made keycap kit --Rabbit Goya --BOOTH](https://booth.pm/ja/items/1783747)
   - Please note that the keycaps for "Kailh low profile (Choc) switches" are not supported as well as the key switches.
- TRS cable ... 1
    - Also called an AUX cable or stereo mini plug cable. It is a cable with so-called earphone plugs attached to both.
      - Good-looking and cheap items are sold on Amazon etc.
    - The elephant42 requires a 3-pole (type with 2 black wires) TRS cable, but you can also use a 4-pole (type with 3 black wires) TRRS cable that is often sold at homebrew keyboard shops. It can be substituted.
      - [TRRS Cable 1m | Yusha Kobo](https://yushakobo.jp/shop/trrs_cable/)
      - [Self-made cable kit | Yusha Kobo](https://yushakobo.jp/shop/self-made-cable/)
      - [Transparent cable --Rabbit Goya --BOOTH](https://illness072.booth.pm/items/2227567)
- USB cable (Type-A to Micro-B) ... 1
    - It is a so-called Micro USB cable.
      - Good-looking items are sold on Amazon etc.
      - [USB Cable Micro B 1m | Yusha Kobo](https://yushakobo.jp/shop/usb_cable_micro_b/)
      - [Self-made cable kit | Yusha Kobo](https://yushakobo.jp/shop/self-made-cable/)
      - [USB2.0 cable (0.6m/USB (A) male--USB (Micro-B) male) | TALP KEYBOARD](https://talpkeyboard.stores.jp/items/5df82904a551d528d7360c34)

### Optional

1. OLED module (with pin socket) ... 2 pcs
    - [OLED module | Yusha Kobo](https://yushakobo.jp/shop/oled/) * Please select with pin socket
1. YS-SK6812MINI-E ... 54 pieces
    - [YS-SK6812MINI-E (10 pieces) | Yusha Kobo](https://yushakobo.jp/shop/ys-sk6812mini-e/) * Please purchase 6 packs (6 pieces left)
    - **The conventional product "[SK6812MINI](https://yushakobo.jp/shop/sk6812mini-35/)" cannot be used because it is not compatible.**
    - **When purchasing at the Yusha Kobo actual store, do not accidentally purchase "[Reverse Mount RGB LED](https://yushakobo.jp/shop/a0800rl-10/)" which looks very similar. be careful. It cannot be used because it is not compatible.**

## Tool Preparations

Tools are required not only for assembly but also for repairs. Also, especially in electronic work, using good tools makes the work much easier.
It's a good idea to consult with your wallet and get the best tools possible.

Also, if there is a work space in a place that is easily accessible from home, you may want to consider using that space.

### Necessary Things

- Solder
  - [Goot High Density Integrated Substrate Solder SD-60](https://www.amazon.co.jp//dp/B0029LGAJI/)
    - Most parts are installed here
  - [Kutomi Denki Sangyo SH-43 Cryogenic Solder](https://www.sengoku.co.jp/mod/sgk_cart/detail.php?code=6A2W-CFJP)
    -- Only the LED (YS-SK6812mini-E) has a risk of breaking at high temperatures, so I am using this just in case.
- Soldering wire
  - [goot solder blotting wire CP-3015](https://www.amazon.co.jp/dp/B001PR1KPQ)
- Soldering iron
  - [White light dial type temperature control soldering iron FX600](https://www.amazon.co.jp/dp/B006MQD7M4)
  - **We strongly recommend that you have a temperature control function**
- Iron stand
  - [HAKKO trowel stand 633-01](https://www.amazon.co.jp/dp/B000TGNWCS)
- flux
  - [goot PCB Flux BS-75B](https://www.amazon.co.jp/dp/B004ANR7KY/)
  - I sometimes see people who say that they can do it without it, but they are almost certainly advanced people who want to brag about their skills. Especially when you turn on the LED, please think that it is almost indispensable.
- Flux cleaner
  - [Tayo Denki Sangyo (goot) Flux Remover BS-T20B](https://www.amazon.co.jp/dp/B07JHJHTYG/)
  - It is not unnecessary if it is a non-cleaning type flux. It is brown and sticky and dirty, and it seems that it will damage the board due to aging, so please use it as much as possible.
- Kimwipe
  - [Nippon Paper Crecia Kim Wipe S-200 mini 62015 1 piece](https://www.amazon.co.jp/dp/B00CWA23P6)
  - Tissue can be used as a substitute, but I don't recommend it.
- Normal tweezers
  - Use the one purchased from Daiso. Shared with plastic model.
- Normal masking tape
  - Use the one purchased from Daiso. Shared with plastic model.
- Stick file
  - Use the one purchased from Daiso. Shared with plastic model.
- Ordinary utility knife
  - Anything is fine as long as it expires. This time, the design knife used in the plastic model is used instead.

### Good Things to Have

- Oil-based pen
  - Used to paint the side of the board. Please prepare your favorite color.
  - POSCA is recommended because of its good coloring. There is no problem with Gundam markers used in McKee and plastic models.
- Normal nippers
  - Use what you purchased at Daiso
  - It is recommended that you do not share good nippers for plastic models as they will damage the blade.
- Epoxy adhesive
  - Use what you purchased at Daiso
- Tester
  - I think it's better to have it, but I'm using a battery, an electronic buzzer, and a lead wire that are just loosely attached.
- Soldering work mat
  - I think it's better to have it, but I'm not using it
- Cutter mat
  - You can use old newspapers or the outer box of this kit as long as you don't damage your desk. This time I used the one used in the plastic model

### Useful for Shopping

Learn from your ancestors.

- [Tool memo required to make Helix keyboard kit | gist.github.com](https://gist.github.com/mtei/6957107a676ddfa85bde0ae41f8fa849)
- [8th "How to make your own keyboard #)
- [What you need to make your own keyboard | How to walk in the hot spring town](https://salicylic-acid3.hatenablog.com/entry/2018/11/24/%E8%87%AA%E4% BD% 9C% E3% 82% AD% E3% 83% BC% E3% 83% 9C% E3% 83% BC% E3% 83% 89% E3% 82% 92% E4% BD% 9C% E3% 82% 8B% E3% 81% 9F% E3% 82% 81% E3% 81% AB% E5% BF% 85% E8% A6% 81% E3% 81% AA% E3% 82% 82% E3% 81% AE #)
- [Tools used to assemble your own keyboard | yfuku blog](https://blog.yfuku.com/entry/keybord_build_tool)

## (For beginners) Studying soldering

The elephant42 will be soldered at a minimum of approximately 200 locations and a maximum of approximately 440 locations to complete.

Especially for those who are new to life or who haven't soldered in a long time since junior high school, it's a good idea to study how to solder.

If you skip here and start suddenly with the desire to complete it quickly, it will not fit in with you. **really.**

Basic operation of soldering

https://youtu.be/ZA-ehWjRfYM

Since the through holes are soldered when mounting ProMicro, tact switch, TRRS jack, etc., it is efficient to learn with this video.

https://youtu.be/oq3Q3n57-B0

It was efficient to learn how to solder surface mount diodes, LEDs, etc. in this video.

https://youtu.be/vqKKElJ1vw0

## Confirmation of the entire assembly process

The Daihuku Keyboiard channel made a great video, so please watch it and check the build !!

[! [I tried to make my own keyboard elephant42 edition | elephant42: Custom Mechanical Keyboard Build](https://img.youtube.com/vi/GmBnI3VYiT4/0.jpg)](https://www.youtube.com/watch?v=GmBnI3VYiT4)

By the way, it would be good to have a high rating and subscribe to the channel !!!!

## QMK firmware Build environment

Instructions for preparing the firmware can be found here.

https://docs.qmk.fm/#/ja/newbs_getting_started

Since elephant42 does not support QMK Configurator or QMK Toolbox, please build the build environment by referring to the above URL.

There is a place to execute `git clone --recurse-submodules https://github.com/qmk/qmk_firmware.git` on the way, but in the case of elephant42

```
git clone --recurse-submodules -b elephant42 https://github.com/illness072/qmk_firmware.git
```

Please.

Also, the part of `make <keyboard>: default` is

```
make elephant42: default
```

Please.

### QMK Environment Construction Troubleshooting

No matter how hard I try the above, **I can't build the environment**, I'm allergic to the command line,
If you have a situation where you can't use anything other than GUI, please see [here](via.md).

However, we would like to make this method **deprecated** for now, and only when using this method **we will not support** advice, answers to questions, etc.
Think of it as insurance when it just doesn't work.

## Pro Micro's measures against baldness

It's not required, but it's good because you won't feel sad if you do it.

Refer to the following articles, etc., and apply epoxy adhesive around the MicroUSB jack to strengthen the terminals.

- [Write QMK_Firmware while preventing moge of ProMicro](https://qiita.com/hdbx/items/2f3e4ddfcadda2a5578e)
- [Use masking tape to safely take measures against moge of ProMicro](https://cnaos.hatenablog.com/entry/2019/03/16/153754)

# Assembly work

## (Optional) Enable OLED option in firmware

**Please do this only when installing OLED. Enabling the OLED option in the firmware without the OLED installed can cause malfunctions.**

Open `keyboards/elephant42/rules.mk` of the QMK firmware` git clone` in the previous chapter with a text editor such as Notepad, and open it.

```
OLED_DRIVER_ENABLE = no # Enable / Disable OLED driver.
```

Modify the part that is as follows. (Change `no` to` yes`)

```
OLED_DRIVER_ENABLE = yes # Enable / Disable OLED driver.
```

Please save this and rebuild it.

```
make elephant42: default
```

## Writing QMK firmware

Plug the Micro USB cable into the Pro Micro, connect it to your PC, and then

```
make elephant42: default: flash
```

Then the writing will be executed. As the process progresses and you are ready to do the actual writing

```
Detecting USB port, reset your controller now ...
```

Is displayed, touch both RST and GND of the connected ProMicro at the same time with tweezers for a moment to short them.

The Pro Micro power light will then flash and the actual writing will begin.

When the following message is displayed at the end, writing is complete.

```
avrdude done. Thank you.
```

Do this for both the left and right Pro Micro.

**At this time, if you pull out the Pro Micro vigorously, the Micro USB jack will come off the board and become unusable. Take great care to pull it out slowly, gently and straight.**

|Connect |Firmware |
|-|-|
| Connect ProMicro to the PC and start the write command | When it is in the standby state, short the RST and GND for a moment to execute the write process |

### QMK Write Troubleshooting

In some environments, the following message may appear when executing a command. In this case, just press Enter and wait for a while, then wait for the write to fail and finish.

```
sh:/tmp/1: Permission denied
.override rw-r--r--root/wheel for/tmp/1? (Y/n [n])
```

If you get an error with the string `permission denied` like this,

```
sudo make elephant42: default: flash
```

I think that you can succeed by rewriting and executing. (You will be asked to enter the password, so enter the password for your account. At this time, the screen will not display anything like `**` or `●●●●`, but it will be It's normal, so don't worry, just enter your password and press Enter.)

## Main board (PCB) partition

Divide the PCB in two. Make a notch with a cutter along the perforation, slowly fold it by hand, and prepare the cross section with a stick file.

**Be careful not to scratch the rest of the board with the cutter.**
**When folding the board, hold it in the immediate vicinity of the target area and apply force so that other parts do not break or bend.**

|Initial state |Make a notch |
|:-: |:-: |
| Take out the PCB and place it on the cutter mat | Make a notch with the cutter along the perforations. <br/> Apply the blade dozens of times with a weak force so as not to damage other parts. |
|Cut |Fold |
| Both sides, all four cuts have been made. | Fold it carefully so that other parts do not break or bend. <br/> If it is hard, do not try to fold it forcibly, and make a deep cut with a cutter. |
|Broken |Sandpaper |
| Both sides broke cleanly. The small piece in the middle is unnecessary and should be thrown away. | The cut surface is jagged and dangerous, so clean it with a stick file. <br/> Since the powder will scatter during the sanding work, it is recommended that you do it in a place that is easy to clean and that you can get dirty. |
|Yasuta |
| It has become beautiful. If you trace the surroundings with your finger and it is flat, it is okay if you can see it with a slight vertical line. |

### (Optional) Color the sides of the PCB

As you can see in the picture, the side of the PCB has a strange color and looks bad, and it looks good even after completion, so it is recommended to paint it.

Trace the sides with an oil-based pen, and wipe off the ink on the front and back with a tissue or Kimwipe.

|Paint color |Dry |
|:-: |:-: |
| Paint the sides of the PCB with a pen. Wipe it off immediately if it sticks out | If you work immediately after that, your hands will get dirty, so let it dry. |

It's common to paint with the same color as the PCB, but it's also nice to have an example of painting with a different color to accentuate it! Also, Pro Micro can be more complete by painting the sides in the same way.

## Soldering Pro Micro and Conthru

Check the orientation of the conthrough and insert it into the Pro Micro by referring to the photo.

It also fits into the main board (PCB) so that the ProMicro and Conslew are mounted at right angles, and then solder the Consul and ProMicro.

**Solder the ProMicro and the conthrough, not the main board (PCB) and the conthrough.**

After soldering the ProMicro and the conthru, remove the ProMicro (and the soldered conthru) from the main board once.

|Consul |Insert into Promicro |
|:-: |:-: |
| Consul has an orientation (windows open/not open). | Align the conthroughs and insert the ProMicro chip into the visible side. |
|Opposite side |Soldering |
| View from the opposite side. Make sure that the conthroughs are oriented in the same direction. | Fit it on the main board (PCB) and solder each pin from above. <br/> (I forgot to take a picture and took it later, so I have something other than ProMicro installed, but please do not see it.) |

It is recommended that you do not cut the legs of the conthrough that protrude from the top of the Pro Micro. The solder part was cracked (cracked), and my foot was completely pulled out from the other side.

## (Optional) Backlight / Underglow LED installation

Installing full-color LEDs is one of the most difficult tasks in the homebrew keyboard world, but with the advent of new LEDs, it has become much easier and safer to install.

Even if you have been frustrated before, why not try again this time?

### Installation of backlight LED

First, install only the backlight LED (left hand: L1 to L21, right hand: L29 to L49). Install a total of 42 pieces, 21 on each side.

If you use flux for soldering, you can easily, cleanly, and firmly bond.

The LED is a very small part, so it's a good idea to take it out and install it little by little so that you don't feel sad when you sprinkle it.

|Temperature setting |Place |
|:-: |:-: |
| Setting the soldering iron temperature lower will greatly reduce the chance of the LED burning out. <br/> Check the melting point of the solder used and work at the lowest possible temperature. | Place the PCB face down (silver pad on top). |
|LED mounting hole |LED layout example |
| The LED is mounted in a square hole labeled Backlight or Underglow in white letters (silk). <br/>**Please install according to the installation number order written as L1, L2, ....**| LEDs are oriented. Place the Backlight downwards and the Underglow upwards. <br/> Also, there is a notch in only one of the four tabs extending from the LED, so make sure that tab is in the'G' position. <br/>**If the orientation is wrong, the LED will not light up, and in the worst case, the keyboard itself may break down. Please place it with the utmost care.**|
|Backlight installation order |Backlight installation example |
| As shown in the figure, attach from the thumb side to the little finger in the order of the white letters L1, L2 ... (silk) near the LED mounting holes. | I soldered L1. Make sure to visually check that the LED tabs are not floating from the board. |

### LED TEST method

If you install the LED, it will be smooth if you check the operation every time you install one to several LEDs.

The firmware for checking the operation of the LED can be written with the following command. Please write by referring to the procedure of [Write QMK firmware] (Write # qmk-firmware-) earlier.

```
make helix: led_test: flash
```

If you insert the ProMicro with this firmware burned into the PCB and connect it to the PC, it will light up in the order of "red → green → blue → red → ...".
You can check whether the soldering is successful by checking whether all the LEDs are lit correctly as "red → green → blue → red → ...".

When the PC is sleeping, it may only glow red and the color may not change.
Test when your PC isn't sleeping normally.

**It looks like it is being installed and tested in a good way**

| | | | | |
|:-: |:-: |:-: |:-: |:-: |
| The backlight of the thumb shines | The index finger also shines | Then the middle finger and ring finger. A little more! | Little finger is complete. This completes the backlight! | Underground is OK. <br/> One-handed all done !! |

### Installation of underglow LED

Once the backlight LED installation is complete and all LED TESTs have passed, the underglow LED (left hand: L22 to L27, right hand: L50 to L55) can be installed. Install 12 on each side, 6 on each side.

|Underglow installation order |Underglow installation example |
|:-: |:-: |
| Next is Underglow. As with the backlight, install in the order of silk numbers. | I installed L27. Please note that the background and underglow are upside down. |

### LED installation troubleshooting

**The mounting holes are too tight to fit the LED**

This may happen due to manufacturing errors in board manufacturing. I intend to inspect it sufficiently, but I'm sorry for the omission.

In such a case, do not force it in, but scrape the inside of the LED hole a little with a stick file to widen the hole.

**Some LEDs do not glow**

It's likely that the non-lighting LED or the previous LED is wrong.

This article is about the previous version of SK6812MINI, not the YS-SK6812MINI-E used for elephant42.
The debugging method is described in detail in this article, so we recommend that you read it carefully.

[I made a cornet keyboard-I have a hard time installing LEDs- | Kiokuno Laundering](https://marksard.github.io/2018/08/04/make-the-crkbd/)

The pin assignment of YS-SK6812MINI-E is as follows, so it is different from that of SK6812MINI. Please read as appropriate.

|LED pin assignment (front) |LED pin assignment (back) |
|:-: |:-: |
| LED pin assignment (front) | LED pin assignment (back) |

**I made a mistake in installing the LED !!**

The important thing about fixing the LED is **don't rush to remove it**.

Basically, unless the LED itself is broken or misoriented, it often works just by reheating or re-soldering from above.

When removing parts, please be careful because if you do not do it carefully and well, the board will be easily damaged and in the worst case it may cause a catastrophe such as peeling of the land.

If the board is damaged, we also sell the board as a single unit, so please use that.

## Installation of diode

Install a total of 42 diodes, 21 on each side. **Please note that the diode is oriented.**

The diode is a very small part, so it's a good idea to take it out and install it little by little so that you don't feel dark when you sprinkle it.

|Before installing diode |After installing diode |
|:-: |:-: |
| `\ | ◁` Attach it where there is silk. Install so that the vertical line of the diode faces the side of `\ |` of `\ | ◁`. |

## Installing the switch socket

Install 21 switch sockets on each side, for a total of 42. **Please note that the socket is also oriented.**

The switch socket isn't a very small part, and it doesn't feel as painful to sprinkle it on, but it's still a good idea to take it out and install it little by little.

|Before installing socket |Notes on socket |
|:-: |:-: |
| Install the socket. Please install according to the silk frame. | Be careful when mounting some diodes as they are very close to the mounting position. |

## Installation of TRRS jack and reset switch

Install one TRRS jack and one reset switch on each side.

**Turn the PCB over, fit it from the front side, then turn it over and solder the back side.**

The TRRS jack will fall off when turned inside out, so it's a good idea to secure it with masking tape.

|Installation example |
|:-: |
| Insert the TRRS jack and switch from the front side, and solder from the back side. **Please note the front and back.**|

If you feel that the TRRS jack or reset switch that pops out of the PCB is too long, cut it a little with nippers to improve its appearance.

## (Optional) OLED installation

When installing an OLED, install the pin socket that came with the OLED.

This is also **fitted from the front side and soldered on the back side.**

The pin socket will fall off when turned inside out, so it's a good idea to fix it with masking tape.

|Installation example |Done |
|:-: |:-: |
| Insert the pin socket from the front side and solder from the back side. **Please note the front and back.**| Insert the pin header into the pin socket, then insert the OLED and solder the OLED to the pin header. |

### Please note only the RC version

**The following issues have been fixed on the v1 board (white board). Please check only the RC version (red board).**

|Caution for the first time |Caution for the first time |
|:-: |:-: |
|**! Attention!**(I'm sorry ...) <br /> In the RC version (initial sale), the clearance between ProMicro and the pin socket is severe. <br/> Install ProMicro first, align the pin socket, and then install. | Also, the RC version (initial sale) has a slight OLED protrusion after completion. Please be assured that there is no problem in operation. |

## Operation check

At this point, all the soldering work has been completed. Let's check if the work so far is done well.

First, install the ProMicro and connect the TRS and USB cables. **Make sure to insert the USB cable on the left hand side.**

If you are burning the firmware for LED TEST with [LED TEST] (# led-test-method), refer to the procedure of [Write QMK firmware] (Write # qmk-firmware-) again to elephant42 firmware. Bake.

At this time, the procedure for short-circuiting GND and RST can be done simply by pressing the mounted reset switch. Also check the operation of the reset switch to see if it can be baked well.

After the connection is complete, use tweezers to short-circuit both sides of the switch socket and check if the switch is recognized as pressed.

In addition to opening a suitable text editor such as Notepad and confirming that the intended key is entered, you can also use the following test sites.

https://www.keyboardtester.com/

|Install ProMicro |Short switch socket |
|:-: |:-: |
| Install ProMicro from the front side, connect all cables, and burn the firmware again. <br/> When installing OLED, install OLED as well. | Short any key socket and see if the key behaves as if it were pressed. **Because you are touching from the back side, the left and right sides are reversed.**|
|Default keymap (left) |Default keymap (right) |
| The default keymap for the left hand. I think it's on the right side because it's turned inside out. | Right hand default keymap. I think it's on the left side because it's turned inside out. |

### Operation check Troubleshooting

**LED does not illuminate**

The behavior is correct as it shouldn't glow if you just burned the default farm.

Raise (right thumb, hold down second from inside) + c to turn the LED on/off.

**Only certain keys do not respond**

The key socket or diode may be defective in soldering, or the diode may be oriented in the opposite direction.

**Enter characters that a particular key did not intend**

There is a high possibility that something is short-circuited. Please check it carefully

**All specific rows and all specific columns do not respond**

Poor insertion of Pro Micro or defective soldering of the con-through is possible.

**All keys do not respond with both hands**

In particular, make sure that the ProMicro on your left is not missing or is installed upside down.

**All keys do not respond only on the right hand side (the one without USB inserted)**

Make sure that the ProMicro on the right hand side is not pulled out and that it is not installed upside down.

Alternatively, the TRS cable may not be fully inserted, or it may be defective.

**Behaves upside down**

First, be aware that you are looking at the keyboard from the back.

If that's the opposite, you're probably plugging the USB cable to your right hand (that is, to the left).

**Both left and right behave as left hand (or right hand)**

I don't really understand it, but it usually works.

1. Unplug the TRS cable and rehash both the left and right elephant42 farms.
2. Insert the TRS cable and re-burn the elephant42 farm with only your left hand.
3. Unplug and reinsert the USB cable

**The default keymap looks like it's for Mac, but I'm using Windows. .. ..**

I'm sorry, I don't have Windows and I haven't confirmed the operation.
The only difference between the two operating systems should be that Opt is treated as Alt and Cmd is treated as Win key.

**Other than that, or the above solution does not solve it**

I'm only worried if I can solve it, but for the time being, please [contact me] (https://twitter.com/illness072/). We will do our best to help you.

Let's do our best and be happy !!

### Flux Cleaning

Once the operation is confirmed, the soldering iron is no longer in play. Apply a flux cleaner and wipe it off with a Kimwipe.

When the board becomes shiny, the tension of the final assembly is different !!

## Screwed

Now, the completion is near.

Carefully peel off the protective paper from the acrylic plate and assemble it carefully to prevent dust, fingerprints and dirt from getting on it for a beautiful finish.

|Installing ProMicro Protective Plate 1 |Installing ProMicro Protective Plate 2 |
|:-: |:-: |
| Screw the spacer onto the ProMicro protective plate. <br/> Use the spacer (long) if the OLED is installed, and the spacer (short) if it is not installed. | In addition, screw the ProMicro protective plate + spacer to the board. |
|Installing the top plate |Installing the middle plate |
| Screw the spacer (short) to the top plate. <br/>**Be careful not to get fingerprints !!**| Place the middle plate on it. <br/>**Be careful not to get dust in!**|
|Installing the PCB |Installing the bottom plate |
| Add more PCB. | Finally, place the bottom plate and screw it in. |
|Cushion rubber installation |Screwed completion |
| Paste the cushion rubber. | Turn it over and the keyboard itself is complete. |
|Installing the keyswitch |Installing the keycap |
| Then attach your favorite key switch ... | Put on the key cap and you're done !! |

If you make both hands and connect the cables, you should have your own elephant42 in front of you. Congrats!!

## (Optional) Rejoice in completion

If you tremble with a sense of accomplishment and finish a small dance,
Why don't you take a picture of the completed elephant42 and upload it to Twitter? ([`# Elephant42`] (https://twitter.com/hashtag/elephant42) I would be very happy if you tweet with a hashtag. Please feel free to give us your opinions and impressions.)

# Customize

Well, the keyboard is complete, but this is just the beginning.

The real attraction of homebrew keyboards is their infinite customizability. Make your keyboard the best keyboard for you.

## Keymap customization

This is what the default keymap looks like, but I want to do this. Isn't it something like that?

You can customize the keymap to your liking by referring to these documents.

[Building the first firmware](https://docs.qmk.fm/#/ja/newbs_building_firmware)
[Edit QMK keymap for the first time](https://qiita.com/marksard/items/9317949ce1da327f7436)

## OLED customization

It's okay to put on OLED, but it's not good. And you who mourn. You can also display your favorite image.

There are many ways to do it, but I use this service. (It's a title like Helix only, but it can be used with elephant42 without any problem)

[I made a service to easily customize Helix's OLED display](https://qiita.com/guri3/items/844675b637c88515a989)

You can change the OLED display by replacing the created file with QMK's keyboards/elephant42/keymaps/default/glcdfont.c and building/writing the firmware.

## Acrylic plate customization

The elephant42 uses an acrylic plate called "Fluorescent Edge Pink", but you don't have to use pink at all.

You can use [Plate Cut Data](https://github.com/illness072/elephant42/tree/master/plates) to make an elephant42 of your favorite color using the acrylic cut service.

- [Laser processing service | Yusha Kobo](https://yushakobo.jp/shop/lasercut/)

## 3D printing of special case

We are also developing a [shining palm rest integrated case](https://github.com/illness072/elephant42/tree/master/cases/v1) exclusively for elephant42.

Try printing with your home 3D printer or various 3D printing services.

In addition, [plate cut data](https://github.com/illness072/elephant42/tree/master/plates) is also available, so I think it will be easier to challenge the completely original case design. .. (Please show me when you make it !!)

# Daily care

## clean up

Due to the fact that the acrylic plate is used as the material for elephant42, fingerprints due to hand grease and dust are liable to adhere due to static electricity.

If you are concerned, we recommend regular disassembly and cleaning with an antistatic cleaner for plastic/acrylic resin.

I often use something called "Acry Sunday Antistatic Cleaner Polycare F70".

## Firmware update

If it's working fine, you don't really need regular firmware updates, but if you want to try out the new features of QMK Configurator, you might want to try it. Familiarize yourself with `git` and try `pull`.

Also, the firmware of elephant42 is updated occasionally, such as changing the design of the OLED display. By all means if you are interested.

# finally

In writing this build guide, I would like to refer to [uzu42 build guide] (https://github.com/nrtkbb/Keyboards/blob/master/uzu42/build_guide_jp.md) by Naru (@nrtkbb). It was. Thank you so much.

The elephant42 is a keyboard that was very strongly influenced by the design philosophy of Fuku (@yfuku_)'s [claw44] (https://booth.pm/ja/items/1283873). It's a very good keyboard, so please try it if you like.

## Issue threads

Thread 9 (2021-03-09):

v2 status and version silkscreen

fi0, 2021-03-09:
Is v2 finalized? The silkscreen shows v1.0 in the master branch. Thank you!

illness072, 2021-03-09:
elephant42 is currently v1.0.  There are no plans for v2.0 yet.

fi0, 2021-03-09:
Thank you for clarifying. I think I misunderstood v2 case as v2 PCB 😄

illness072, 2021-03-09:
I'm sorry it's complicated!😂

Closed 2021-03-09.

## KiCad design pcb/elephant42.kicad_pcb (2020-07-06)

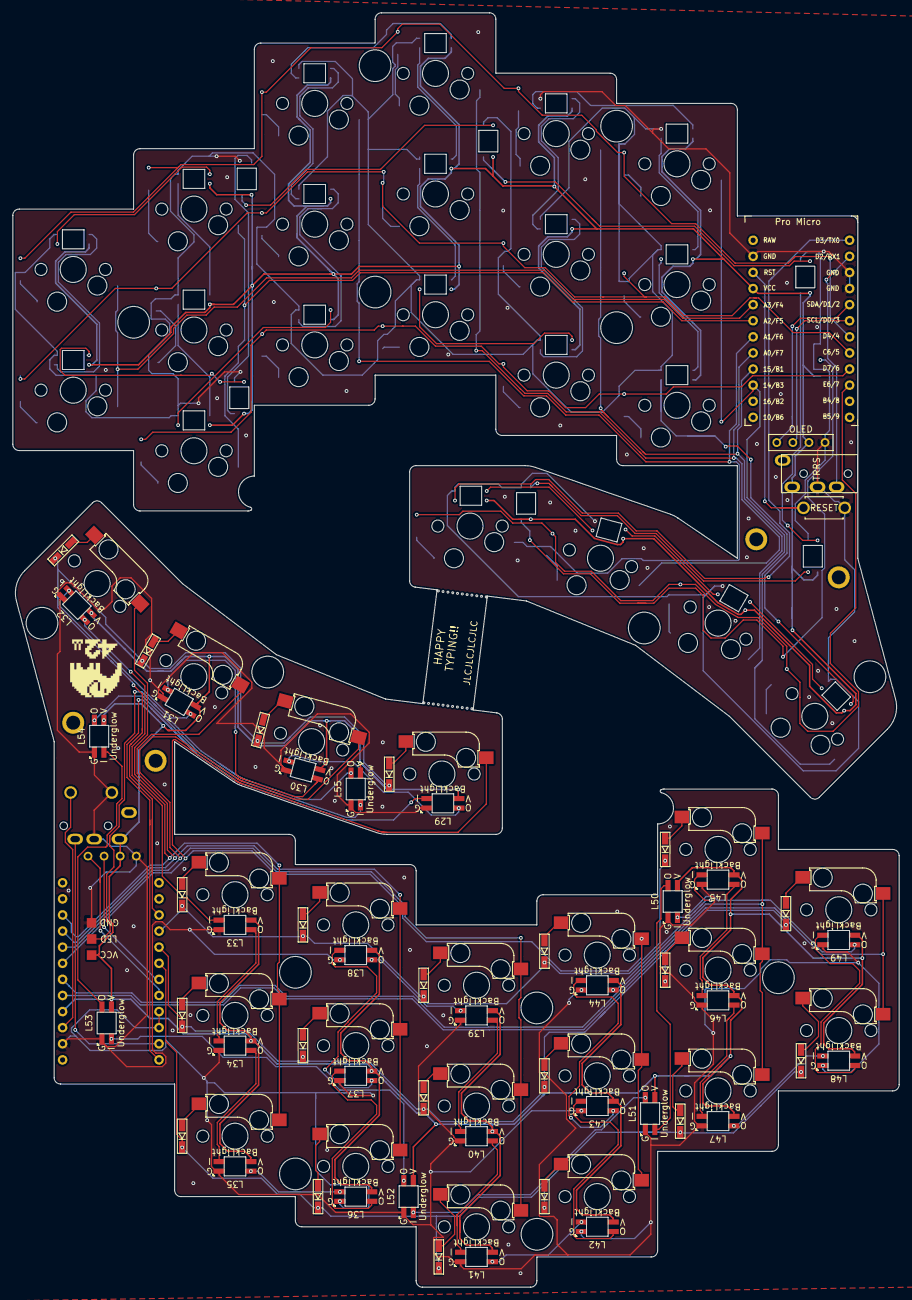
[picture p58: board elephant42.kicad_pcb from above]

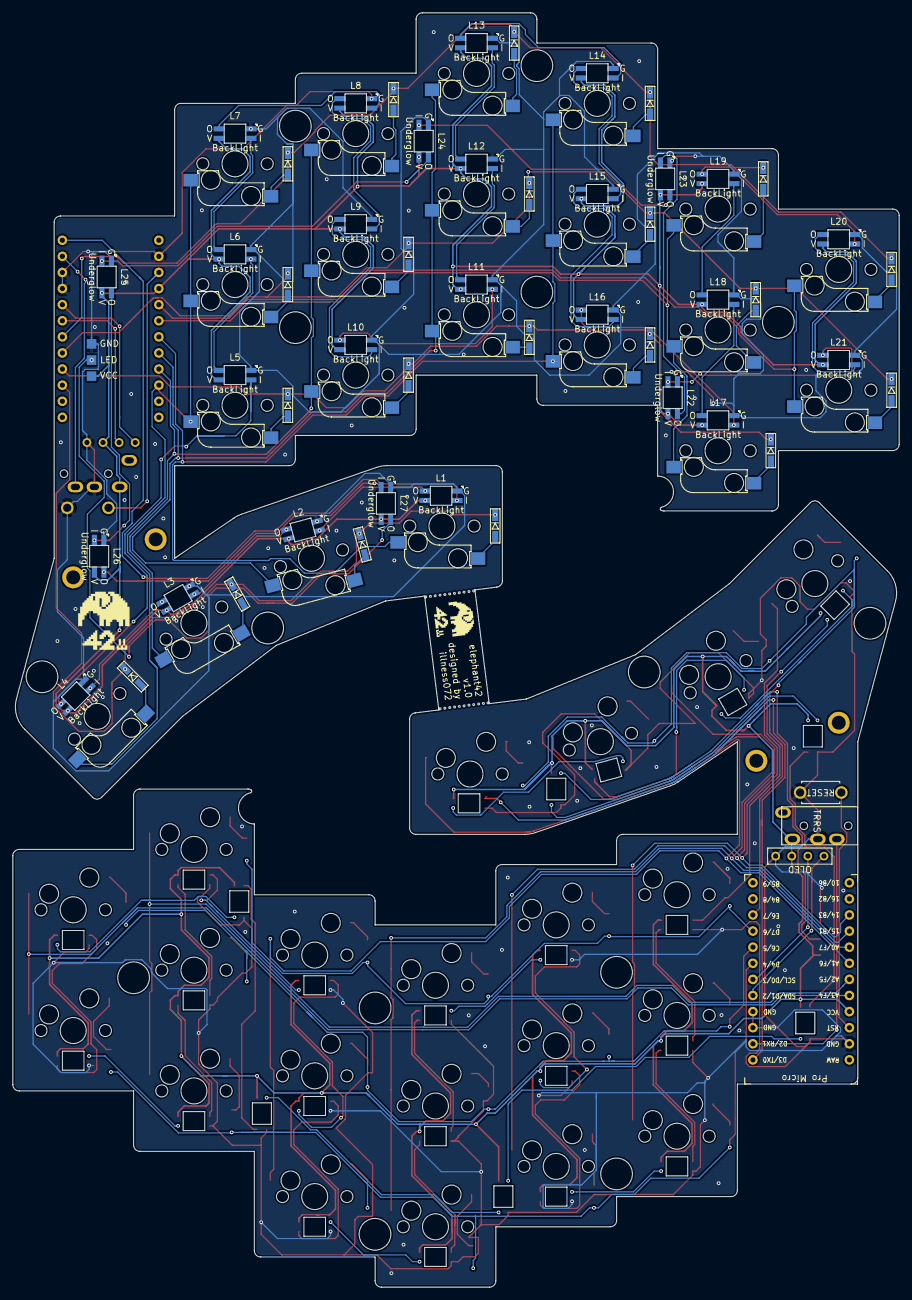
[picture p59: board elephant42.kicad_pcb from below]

Board: 2 copper layers, 139.8 x 201.0 mm, 152 parts (74 on the bottom side), 128 nets.

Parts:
D1, D2, D3, D4, D5, D6, D7, D8, D9, D10, D11, D12, D13, D14, D15, D16, D17, D18, D19, D20, D21, D22, D23, D24, D25, D26, D27, D28, D29, D30, D31, D32, D33, D34, D35, D36, D37, D38, D39, D40, D41, D42: D; D3_SMD_v2
J1, J3: MJ-4PP-9; MJ-4PP-9_1side
J4, J4#2, J4#3, J4#4: Conn_01x01; M2hole
L1, L2, L3, L4, L5, L6, L7, L8, L9, L10, L11, L12, L13, L14, L15, L16, L17, L18, L19, L20, L21, L29, L30, L31, L32, L33, L34, L35, L36, L37, L38, L39, L40, L41, L42, L43, L44, L45, L46, L47, L48, L49: YS-SK6812mini-E; YS-SK6812MINI-E
L22, L23, L24, L25, L26, L27, L50, L51, L52, L53, L54, L55: YS-SK6812mini-E; YS-SK6812MINI-E-underglow
L28, L56: LED; StripLED_1side
OL1, OL2: OLED; OLED_1side
RESET_SW1, RESET_SW2: SW_PUSH; ResetSW_1side
SW1, SW2, SW3, SW4, SW5, SW6, SW7, SW8, SW9, SW10, SW11, SW12, SW13, SW14, SW15, SW16, SW17, SW18, SW19, SW20, SW21, SW22, SW23, SW24, SW25, SW26, SW27, SW28, SW29, SW30, SW31, SW32, SW33, SW34, SW35, SW36, SW37, SW38, SW39, SW40, SW41, SW42: SW_PUSH; CherryMX_Hotswap
U1, U2: ProMicro; ProMicro_v3

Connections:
GND: J1.C, J3.C, L1.3, L2.3, L3.3, L4.3, L5.3, L6.3, L7.3, L8.3, L9.3, L10.3, L11.3, L12.3, L13.3, L14.3, L15.3, L16.3, L17.3, L18.3, L19.3, L20.3, L21.3, L22.3, L23.3, L24.3, L25.3, L26.3, L27.3, L28.3, L29.3, L30.3, L31.3, L32.3, L33.3, L34.3, L35.3, L36.3, L37.3, L38.3, L39.3, L40.3, L41.3, L42.3, L43.3, L44.3, L45.3, L46.3, L47.3, L48.3, L49.3, L50.3, L51.3, L52.3, L53.3, L54.3, L55.3, L56.3, OL1.4, OL2.4, RESET_SW1.2, RESET_SW2.2, U1.3, U1.4, U1.23, U2.3, U2.4, U2.23
unnamed: D1.2, SW1.2
unnamed: D2.2, SW2.2
unnamed: D3.2, SW3.2
unnamed: D4.2, SW4.2
unnamed: D5.2, SW5.2
unnamed: D6.2, SW6.2
unnamed: D7.2, SW7.2
unnamed: D8.2, SW8.2
unnamed: D9.2, SW9.2
unnamed: D10.2, SW10.2
unnamed: D11.2, SW11.2
unnamed: D12.2, SW12.2
unnamed: D13.2, SW13.2
unnamed: D14.2, SW14.2
unnamed: D15.2, SW15.2
unnamed: D16.2, SW16.2
unnamed: D17.2, SW17.2
unnamed: D18.2, SW18.2
unnamed: D19.2, SW19.2
unnamed: D20.2, SW20.2
unnamed: D21.2, SW21.2
unnamed: D22.2, SW22.2
unnamed: D23.2, SW23.2
unnamed: D24.2, SW24.2
unnamed: D25.2, SW25.2
unnamed: D26.2, SW26.2
unnamed: D27.2, SW27.2
unnamed: D28.2, SW28.2
unnamed: D29.2, SW29.2
unnamed: D30.2, SW30.2
unnamed: D31.2, SW31.2
unnamed: D32.2, SW32.2
unnamed: D33.2, SW33.2
unnamed: D34.2, SW34.2
unnamed: D35.2, SW35.2
unnamed: D36.2, SW36.2
unnamed: D37.2, SW37.2
unnamed: D38.2, SW38.2
unnamed: D39.2, SW39.2
unnamed: D40.2, SW40.2
unnamed: D41.2, SW41.2
unnamed: D42.2, SW42.2
unnamed: L1.2, L2.4
unnamed: L2.2, L3.4
unnamed: L3.2, L4.4
unnamed: L4.2, L5.4
unnamed: L5.2, L6.4
unnamed: L6.2, L7.4
unnamed: L7.2, L8.4
unnamed: L8.2, L9.4
unnamed: L10.2, L11.4
unnamed: L9.2, L10.4
unnamed: L11.2, L12.4
unnamed: L12.2, L13.4
unnamed: L13.2, L14.4
unnamed: L14.2, L15.4
unnamed: L15.2, L16.4
unnamed: L16.2, L17.4
unnamed: L17.2, L18.4
unnamed: L18.2, L19.4
unnamed: L19.2, L20.4
unnamed: L20.2, L21.4
unnamed: L21.2, L22.4
unnamed: L22.2, L23.4
unnamed: L23.2, L24.4
unnamed: L24.2, L25.4
unnamed: L25.2, L26.4
unnamed: L26.2, L27.4
unnamed: L27.2, L28.2
unnamed: L29.2, L30.4
unnamed: L30.2, L31.4
unnamed: L31.2, L32.4
unnamed: L32.2, L33.4
unnamed: L33.2, L34.4
unnamed: L34.2, L35.4
unnamed: L35.2, L36.4
unnamed: L36.2, L37.4
unnamed: L37.2, L38.4
unnamed: L38.2, L39.4
unnamed: L39.2, L40.4
unnamed: L40.2, L41.4
unnamed: L41.2, L42.4
unnamed: L42.2, L43.4
unnamed: L43.2, L44.4
unnamed: L44.2, L45.4
unnamed: L45.2, L46.4
unnamed: L46.2, L47.4
unnamed: L47.2, L48.4
unnamed: L48.2, L49.4
unnamed: L49.2, L50.4
unnamed: L50.2, L51.4
unnamed: L51.2, L52.4
unnamed: L52.2, L53.4
unnamed: L53.2, L54.4
unnamed: L54.2, L55.4
unnamed: L55.2, L56.2
VCC: J1.D, J3.D, L1.1, L2.1, L3.1, L4.1, L5.1, L6.1, L7.1, L8.1, L9.1, L10.1, L11.1, L12.1, L13.1, L14.1, L15.1, L16.1, L17.1, L18.1, L19.1, L20.1, L21.1, L22.1, L23.1, L24.1, L25.1, L26.1, L27.1, L28.1, L29.1, L30.1, L31.1, L32.1, L33.1, L34.1, L35.1, L36.1, L37.1, L38.1, L39.1, L40.1, L41.1, L42.1, L43.1, L44.1, L45.1, L46.1, L47.1, L48.1, L49.1, L50.1, L51.1, L52.1, L53.1, L54.1, L55.1, L56.1, OL1.3, OL2.3, U1.21, U2.21
col0: SW1.1, SW7.1, U1.20
col1: SW2.1, SW8.1, SW13.1, U1.19
col2: SW3.1, SW9.1, SW14.1, SW18.1, U1.18
col3: SW4.1, SW10.1, SW15.1, SW19.1, U1.17
col4: SW5.1, SW11.1, SW16.1, SW20.1, U1.16
col5: SW6.1, SW12.1, SW17.1, SW21.1, U1.15
col6: SW27.1, SW33.1, U2.20
col7: SW26.1, SW32.1, SW38.1, U2.19
col8: SW25.1, SW31.1, SW37.1, SW42.1, U2.18
col9: SW24.1, SW30.1, SW36.1, SW41.1, U2.17
col10: SW23.1, SW29.1, SW35.1, SW40.1, U2.16
col11: SW22.1, SW28.1, SW34.1, SW39.1, U2.15
data_l: J1.B, U1.2
data_r: J3.B, U2.2
led_l: L1.4, U1.1
led_r: L29.4, U2.1
reset_l: RESET_SW1.1, U1.22
reset_r: RESET_SW2.1, U2.22
row0: D1.1, D2.1, D3.1, D4.1, D5.1, D6.1, U1.7
row1: D7.1, D8.1, D9.1, D10.1, D11.1, D12.1, U1.8
row2: D13.1, D14.1, D15.1, D16.1, D17.1, U1.9
row3: D18.1, D19.1, D20.1, D21.1, U1.10
row4: D22.1, D23.1, D24.1, D25.1, D26.1, D27.1, U2.7
row5: D28.1, D29.1, D30.1, D31.1, D32.1, D33.1, U2.8
row6: D34.1, D35.1, D36.1, D37.1, D38.1, U2.9
row7: D39.1, D40.1, D41.1, D42.1, U2.10
scl_l: OL2.2, U1.6
scl_r: OL1.2, U2.6
sda_l: OL2.1, U1.5
sda_r: OL1.1, U2.5

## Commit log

2019-12-01 added plate data
    [bottom.dxf, middle.dxf, protector.dxf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]
2019-12-01 added PCB data
    [elephant42.kicad_pcb, elephant42.sch]
2019-12-01 added case data.
    [base-l.stl, base-r.stl, hanger-l.stl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]
2019-12-20 add LED
    [elephant42.kicad_pcb, elephant42.sch]
2020-01-09 small fix
    [elephant42.kicad_pcb, elephant42.sch]
2020-01-15 update plates
    [acril-cut-2mm-A4.dxf, acril-cut-3mm-A4.dxf, acril-cut-3mm-A5.dxf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]
2020-01-15 update cases
    [base-l.stl, base-r.stl, hanger-l.stl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]
2020-01-20 update build-guide: split PCB, LED
2020-01-20 update build-guide: solder complete
2020-01-20 update build-guide: assemble complete
2020-05-27 fix th
    [elephant42.kicad_pcb, elephant42.sch]
2020-07-04 v1 pcb
    [elephant42.kicad_pcb]
2020-07-06 add cases
    [hanger-L.stl, hanger-R.stl, middle-hanger_L.stl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]
2020-12-26 add v2 case
    [hangerL.stl, hangerR.stl, parmlestL.stl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]
2021-03-08 Fixes a couple more little things
2022-05-16 Add files via upload (#10)
    * Add files via upload
    Add plate data for Yusha-Kobo laser cut
    * Fix plate data
